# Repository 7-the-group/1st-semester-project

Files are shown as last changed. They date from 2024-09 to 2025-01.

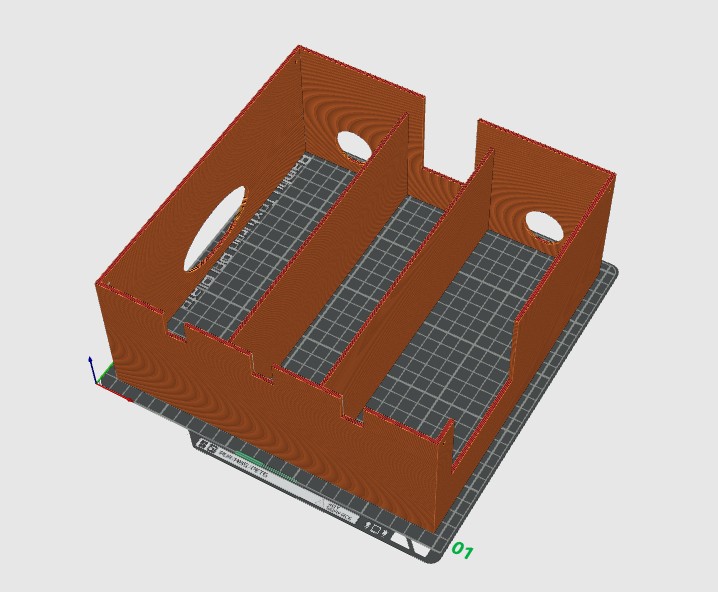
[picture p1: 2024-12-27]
report/figures/walls(3D-Print).jpg

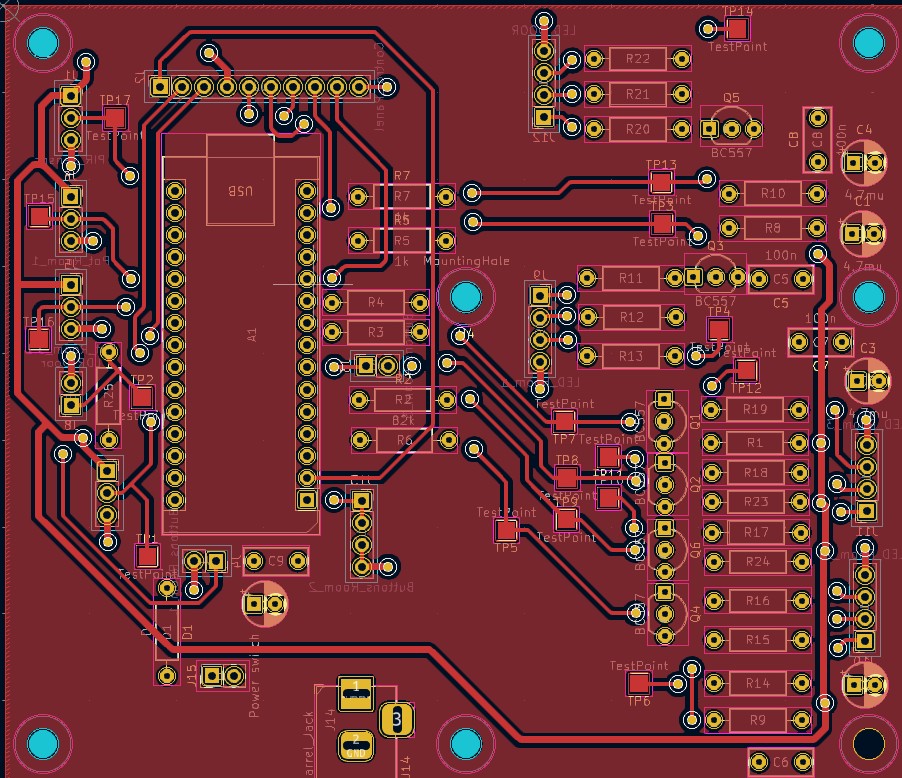
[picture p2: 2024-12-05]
Hardware/Schematic_and_PCB/Arduino Main PCB/arduino main fin/Toplayer.jpg

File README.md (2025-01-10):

# Group 7 semester project

# How to start

All the necessary parts are in Product folder. In Product/PCB there are two zip files for PCB manufacturing one is for PCB with the Arduino and the other one is for PCB with buttons. When PCBs are printed and assembled refer to the documentation appendices for correct connection.

In Product/Models folder you can find .stl files for control panel casing and base. We also created casings for potentiometers and buttons however those serve only esthetic function. Next there is .dxf file, which contains walls model for laser cutter.

Finally in Product/Software folder is PlatformIO project with all the necessary code, just upload it to Arduino.

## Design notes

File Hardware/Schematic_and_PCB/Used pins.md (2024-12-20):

LEDs need pins capable of generating PWM signal, in pinout pdf they are marked with '~'.

For LCD we need I2C pins.

For LDR and potentiometers we need analog pins, those are ones with 'A' prefix.

|Device|Device pin|Arduino pin|Port|
|----|----|----|----|
|LCD|SDA|D18|PC4|
|LCD|SCL|D19|PC5|
|Button up|-|D7|PD7|
|Button down|-|D8|PB0|
|RGB LED room 1|-|D9|PB1|
|Button ok|-|D11|PB3|
|Button back|-|D12|PB4|
|Potentiometer LCD|-|A0(D14)|PC0|
|Button room 1|-|A1(D15)|PC1|
|Light sensor door|-|A3(D17)|PC3|
|Potentiometer room 1|-|A6|ADC6|
|Red LED room 3|-|~D3|PD3|
|Button room 3|-|D4|PD4|
|Green LED room 3|-|~D5|PD5|
|Blue LED room 3|-|~D6|PD6|
|Buttons room 2|-|A2|PC2|
|Button sleep|-|D1 (RX1)|PD1|
|RGB LED room 2|-|D2|PD2|
|Potentiometer room 3|-|A7|ADC7|
|PIR sensor|-|D13|PB5|
|LED door|-|D10|PB2|

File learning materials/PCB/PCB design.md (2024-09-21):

# PCB design

For PCB design we can use [KiCAD](https://www.kicad.org/), [Eagle](https://www.autodesk.com/products/eagle/overview) or [EasyEDA](https://easyeda.com/).

KiCAD - I used KiCAD the most and I prefer it over Eagle also it is more beginner friendly, but now we have everything from autodesk for free I would try Eagle. KiCAD has built in 3D visualizer of PCB.

Eagle - We can use it in combination with [Fusion 360](https://www.autodesk.com/education/edu-software/fusion).

EasyEDA - This application is web based (but can be downloaded as an application). It is designed to be as easy as possible and you can directly order PCBs from [JLC-PCB](https://jlcpcb.com/) in EasyEDA

## Youtube channels and learning resources

[Phil's lab](https://www.youtube.com/@PhilsLab) - He is mostly using KiCAD and Altium designer.

https://resources.pcb.cadence.com/blog/2023-an-introduction-to-printed-circuit-boards

https://www.youtube.com/watch?v=MsdJgEinb34

We are not going to do very complicated circuits, so basic understanding of PCB design and orientation PCB design software should be enough.

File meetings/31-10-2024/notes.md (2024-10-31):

- button approved for printing
- Question: How to connect the components flexibly - jumper cables?
- Battery problem - fix with filtering or use power bank instead? - we will use Milan's power bank - permanent solution
  
PCB design:
- built-in - transistors, resistors, connectors  
- outside - LEDs, buttons, sensors (PIR,LDR), potentiometers, LCD  
 
PCB design assigned to:  
- Jakub - LCD PCB + footprints
- Kati  - Main PCB  
  
How to create libraries 
- .h(declarations) and .c(definition) file
- .h file should have at the start #pragma once or stuff with #ifndef

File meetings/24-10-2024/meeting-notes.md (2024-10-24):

- 3d models and calculations should be ready by Monday
- hardware & circuits tested: lcd, rgb led, photoresistor, pir sensor
- for photoresistor circuit - voltage divider is used
- problems with pir sensor testing, code did not work

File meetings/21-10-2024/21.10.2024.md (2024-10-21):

## Changes in PCB
We settled down on using two potentiometers in room 3 and we connect buttons in room 2 in parallel so they occupy only one pin. Last pin can be used for button for sleep or other functionality.

## 3D model of the house
We diced to route cables in a hollow floor. Overall design has one corridor in the middle and two rooms on the sides. Corridor is the room 2 at the same time.

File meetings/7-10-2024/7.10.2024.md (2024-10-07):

We decided on parts to buy and agreed on using KiCad for PCB design.

Parts are in components.xlsx file.

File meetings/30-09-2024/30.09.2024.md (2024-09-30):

- We will use knob on a LCD display.
- Everyone should write their own list of parts he/she need.
- 

## We decided on a diode
Kingbright Lysdiode 4 ben Hulmontering trefarvet LED RGB 465 / 525 / 630 nm 900 mcd, 1300 mcd, 3600 mcd 2,5 V, 4 V 50°
(https://dk.rs-online.com/web/p/lysdioder/8614290?gb=s)

## We decided on a transistor
BC547

## Parts
- 4x RGB LEDs 
- 1x Knob
- 6x transistors
- 4x buttons for LCD
- 4x light switches (buttons)
- 1x light sensor
- 1x PIR sensor (sensor for movement)
- 3x potentiometers

## Optional parts
- 4x humidity/temperature sensors

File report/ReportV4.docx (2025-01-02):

# Smart home model

Authors:

Milan Caban

Jakub Dubrava

Katharina Lea Johannsen

Roko Grgic

Danylo Lysechko

Yumna Ayesha

# 1 Abstract

This semester’s project focused on designing and building a functional smart home model equipped with a centralized control panel for managing room-specific features such as lighting and PIR sensor. The model demonstrates how modern technology can enhance convenience, energy efficiency, and user interaction within residential spaces. Since this is a first experience with electronic product design for most of the members, we expect that this journey will teach us a lot about electronics and teamwork.

# Table of Figures

# 2 Introduction

This report encompasses various procedures involved in construction of a smart home model. One of the initial definitions of smart home is provided by Lutolf, defining it as “an integration of different services within a home by using a common communication system.” Moreover, it should assure „an economic, secure, and comfortable operation of the home and include a high degree of intelligent functionality and flexibility.” (Lutolf, 1992) A fresher definition by Satpathy states, that “a home which is smart enough to assist the inhabitants to live independently and comfortably with the help of technology is termed as smart home. In a smart home, all the mechanical and digital devices are interconnected to form a network, which can communicate with each other and with the user to create an interactive space.” (Satpathy, 2006) We consider this definition more proper, as it emphasizes the role of network in smart home systems, in contrast to the vaguer term ‘common communication system’ used by Lutolf.

According to Zielonka, one of the major development trends related to smart homes are healthcare and quality of life, security in data management and optimal energy management and sustainability. Presumably, the trend of energy management and sustainability is intertwined with recently rising ecological trend (Zielonka, et al., 2021). However, the graph in Figure 1 shows that advanced lighting and intelligent energy management are not amongst the most influential trends. Nevertheless, the upcoming paragraph underlines the significance of innovation in this sector.

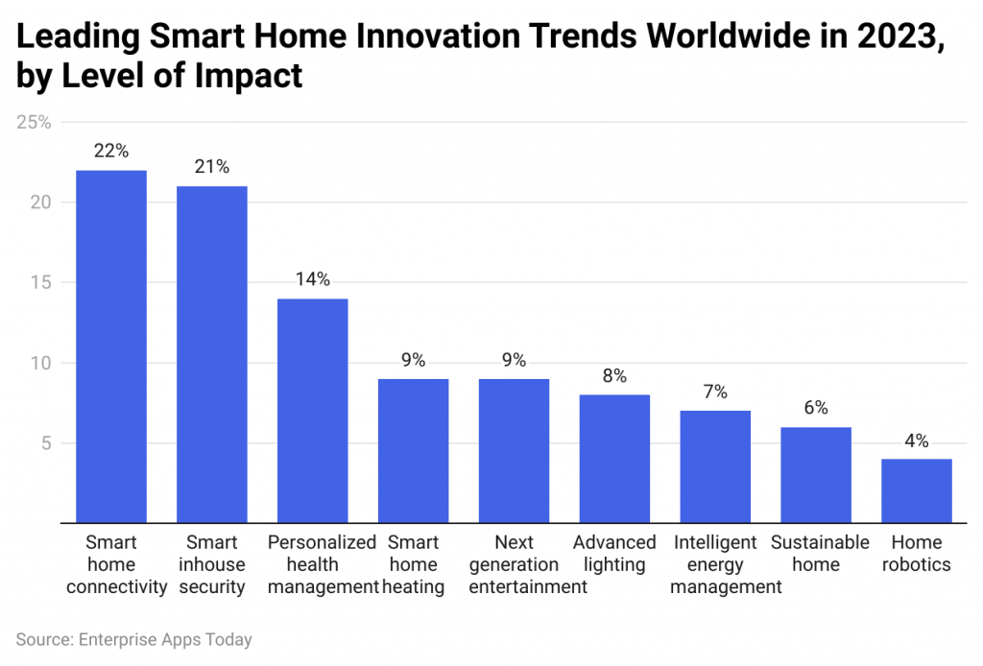
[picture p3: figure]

Figure 1 Graph of Leading Smart Home Innovation Trends Worldwide in 2023

The use of LEDs as an illumination component is crucial not only for lower energy consumption in comparison to conventional lightning bulbs. According to Schratz, “when compared to incumbent lighting technologies, most LED fixtures deliver at least a 50% improvement in energy savings, which translates directly into significantly lower carbon emissions and a much smaller environmental impact”, while they offer more advantages such as “less heat output, lower risk of ignition due to dust and particle accumulation, improved color rendering for a better quality of light, and negligible UV light output, which reduces insect infestation and product deterioration”. Remarkably, its life-span can reach “more than 100,000 operating hours”. (Schratz, Christine, Struhs, & Gray, 2016)

Although lights with movement sensors are commonly used nowadays, they could benefit from integration into a centralized system, bringing everything ‘under one roof’. The main advantage of a system with a centralized unit is its flexibility, as users would be able to manipulate light status manually inside the house as well as through communication with the centralized unit, for instance via a control panel. New features could be implemented, for example allowing the change of various thresholds according to user’s needs easily and any time.

However, many challenges emerged during the design process. The most significant problems can be summarized in several ‘how to’ questions:

1. How to construct the house?
2. How to adjust the intensity or color of the light?
3. How to assemble and integrate the circuits?
4. How to structure the control panel menu?

Mentioned questions are answered in subsequent 8 sections. The third chapter includes detailed steps of the design process, where any decision is complemented by justification. The fourth section concerns the final product, possibly deviating from the planned design. The fifth section contains comparison of design and result as well as technical limitations. Moreover, the sixth section provides a concise conclusion on the whole project. References and appendices are placed in the last two sections.

# 3 Methods

## 3.1 Circuit design

### 3.1.1 Control panel PCB

We chose to have a Control panel, because according to Alam, a characteristic of a smart home is that it can be controlled remotely from outside the home. (Alam, Reaz, & Ali, 2012) The control panel could be developed further to be wireless with Bluetooth and controlled via an app.

For the Control panel, we chose to use buttons to navigate in a menu displayed on the LCD.

A Potentiometer was planned to control the RGB Values and the brightness of the LEDs.

We incorporated 5 buttons UP, DOWN, OK, BACK and a Button for an extra function (sleep mode).

The 4k7 Ω Resistors function as Pull up Resistors for the I2C Module of the LCD.

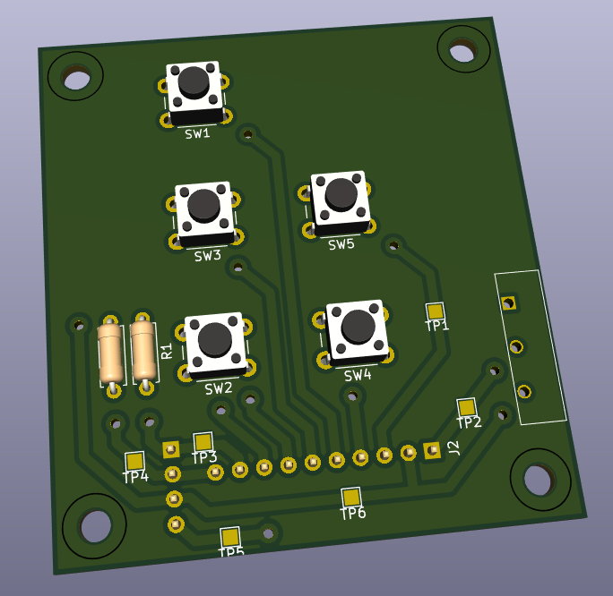
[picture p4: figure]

Figure 2 Control panel PCB 3D model

### 3.1.2 Main PCB

We decided to have the components in and on the house (switch-buttons, LED, Potentiometer, Sensors) connected to the PCB with pin header connectors. So, the PCB is detachable from the House. We Further divided the circuit in two PCB’s. One for the Control panel, with the Buttons and Potentiometer mounted on the PCB via Through hole soldering and a pin header connection to the Liquid Crystal Display (LCD).

The other PCB has the transistor driver circuit for the LED's, circuits for the Sensors and the microcontroller on It.

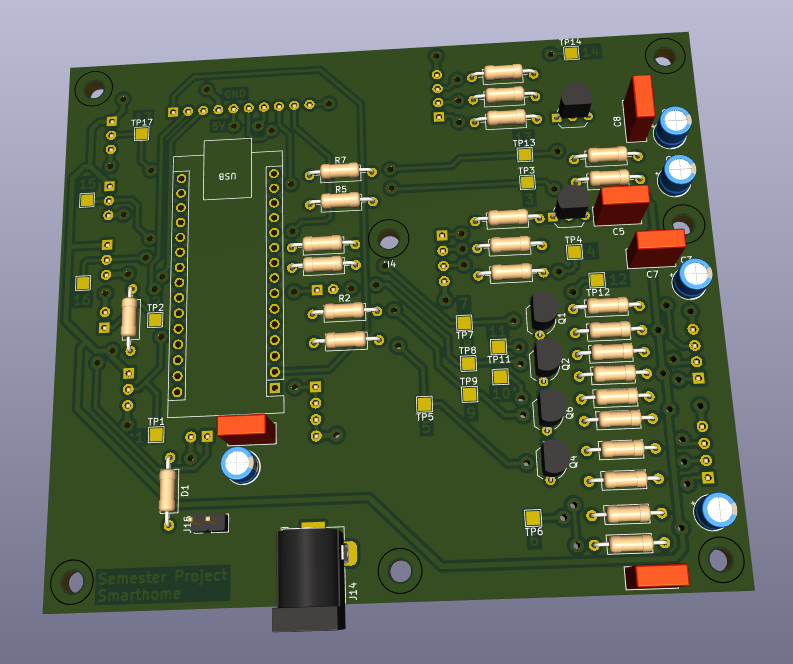
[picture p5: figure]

Figure 3 Main PCB 3D model

## 3.2 3D-Modelling

The design of the house can be divided into two categories, one is base and the other are walls and floor.

The base was designed in Fusion 360 for 3D printer. The whole model consists of 230mm X 230mm square with three rooms. We also added mounting holes for walls and floor and space under the floor is empty for routing cables, for that reason we also added openings at the back near the control panel.

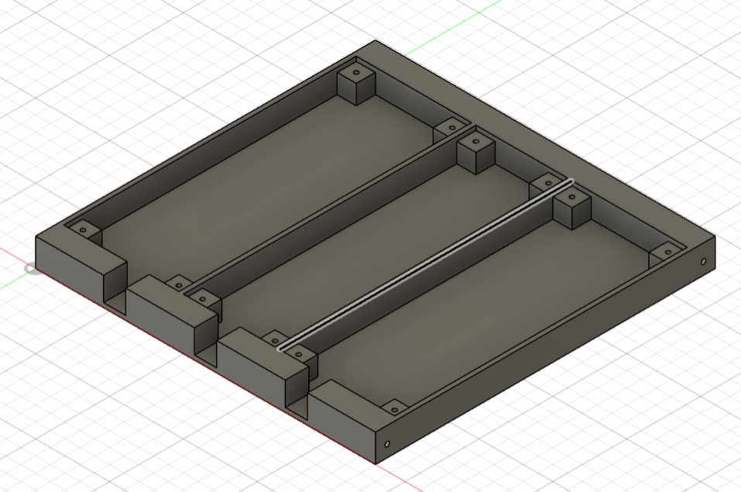
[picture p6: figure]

Figure 4 Base 3D model

Walls and floor were designed in Fusion 360 as well, but they were designed for a laser cutter. After laser cutting some parts had to be treated using a rasp so they fit together, because some connections are angled 45 degrees for stronger fit.

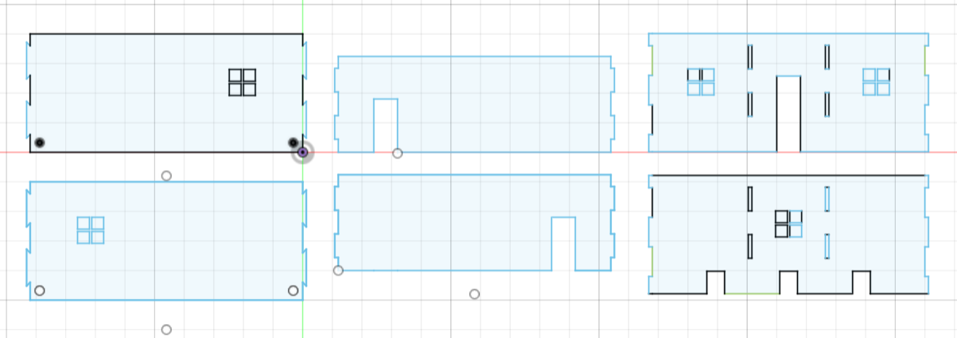
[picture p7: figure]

Figure 5 Walls and floor model

For slicing we used Bambu Studio and printed it as well with a Bambu 3D printer.

## 3.3 Assembly of the Model

After receiving the drilled PCBs, we checked the connections with a multimeter.

Because the PCBs had no connection errors, we continued with the next step: soldering the PCBs.

To have more space underneath the PCB when placing it on the table, we first soldered some of the pin headers to make it stand stable while soldering the vias.

Then we soldered the components starting with the flattest and ending with the tallest.

We reused the female-to-female jumper cables to create the wiring to the components in the house. So, the cables were cut in half and soldered to flex wire around 475 mm in length. Then the flex wires were soldered to the components according to the color-coded wiring table. We used shrinkable tubes to isolate the soldered wire to prevent short circuits. Now with the wiring the entire system and code could be tested.

The Control Panel PCB was mounted with four M3 x 40 mm screws and 20 mm long spacers on to the Mainboard.

Where the LEDs should go, 5mm holes got drilled in the walls for the Lens to go through. To mount the LDR sensor and the PIR sensor, holes were drilled in the outer walls as well.

To arrange the LEDs, buttons and sensors in the house, it was marked where the wires go through the floor. According to that, the floor plates got holes drilled through the wood.

With the components placed on the walls, the female connectors were thread through the holes in the floor, routed at the bottom and lead to the casing of the Control Panel.

The LCD was mounted to the lid of the control panel casing with four M3 x 10 mm screws and nuts.

With all the connections according to the wiring table, the casing of the control panel could be closed and the walls screwed to the bottom with four 3.5 x 25 mm spax screws. To fix the wires on the walls we used electrical tape.

## 3.4 Problems during assembly

On the Main PCB connection issues and other connection issues were discovered while testing the connections with a multimeter. We fixed the problem with resoldering the visual faulty solder joints.

We realized that D0 was just connected on top layer on the Main PCB Layout, a via was forgotten to be placed in front. Fortunately, it was not relevant for the main functionality because it was meant to be for an optional button to start an extra function.

The Wire for Room 1 Button was swapped with Room 1 Pot, because the IO Pin A6 formerly assigned to Room 1 Button can only be used analog.

The Potentiometer on the control panel was not implemented because it was more convenient to code the user interface only with buttons.

The Pin D1/RX was not able to be used because it interfered with serial communication (RX/TX), even without being connected to a PC. That was probably caused by the USB C connector circuit on the microcontroller. D1 was originally used for button room 2 but then changed to A2. Because J5 had just one pin connected to A2, the two wires of the buttons in parallel were soldered to one female connector.

## 3.5 Introduction to software

Our first idea was to create a library for every room, door and control panel. The library should implement “Init()” and “Update()” functions which will be called in main function. In addition to them, we also implemented some functions which control the state of the room directly, for example they turn the light on and off. This approach made code more maintainable and readable, therefore we used it in our final build. Also, we could very easily divide individual code parts to team members, in our case everyone had to program one room.

Figure 6 Main program

We had to come up with a solution to how buttons should operate in rooms where there is the possibility to change brightness or color of the light. After a few discussions we stuck to the idea that the last action takes effect. This means that if brightness was set to half of its potential by clicking the button the light is turned off (light is set to maximum brightness after clicking button, only when brightness is zero), even though the potentiometer’s value stays unchanged. This solution turned out to be very handy when we started working on the control panel.

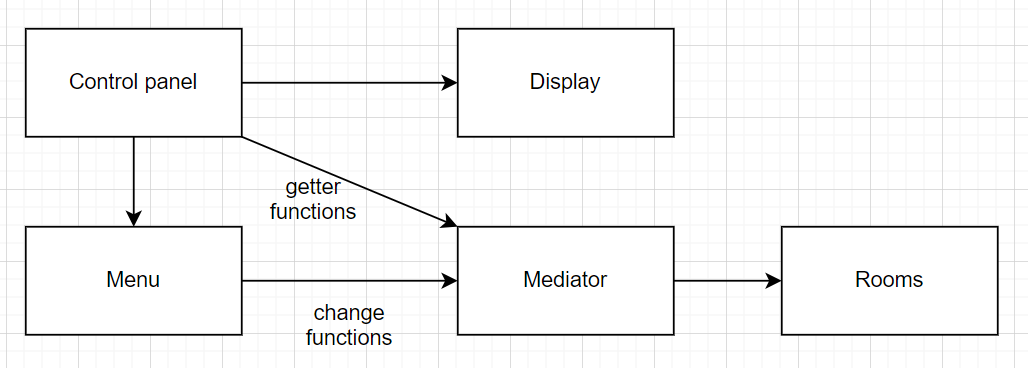
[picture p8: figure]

Figure 7 Software diagram

When a button is pressed the change from not being pressed and being pressed isn’t immediate, there are always some fluctuations which are the result of mechanical construction of a button. We solved this issue by adding delay every time a button is pressed, this resulted in functions for every button which check status of a button and if it is pressed, they start a 100 ms delay.

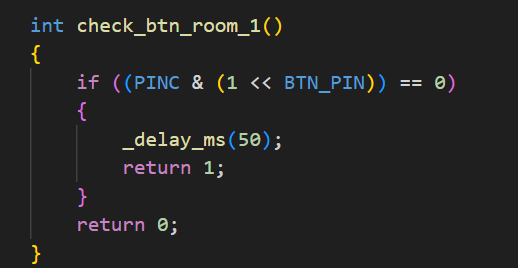
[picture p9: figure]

Figure 8 Check button function

## 3.6 Room 1 software

Room 1 has one button for turning the LED on and off and one potentiometer for controlling the brightness of the LED. We implemented functions for controlling and retrieving information about the LED’s status and brightness.

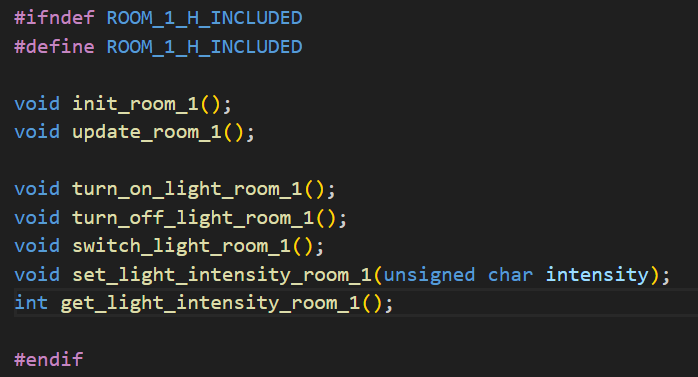
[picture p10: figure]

Figure 9 Room1.h

In “Init()” we initialized ADC and PWM using Alin’s libraries and set button pin as input with pull up resistor. To do that we referred to AtMega datasheet (Atmel Corporation, 2015) and Arduino Nano pinout (Arduino cc, 2021). We used these documents for other rooms and control panel as well.

“Update()” function checks if potentiometer values changed since last measurement, if yes update LED’s intensity accordingly. Then it checks if button is pressed and wasn’t pressed previously, if this statement is true then the status of LED is inverted.

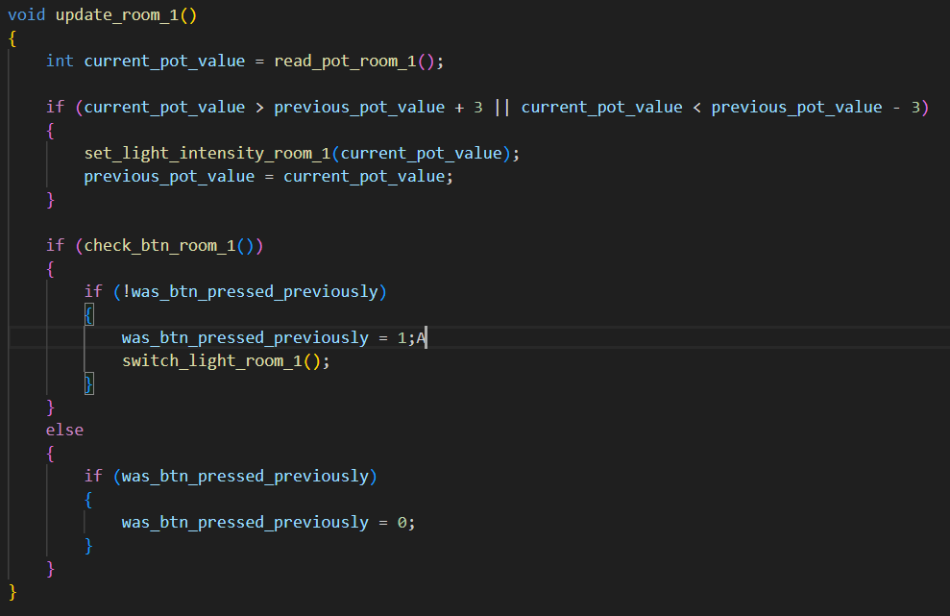
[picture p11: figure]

Figure 10 Update room 1 function

## 3.7 Room 2 software

This is the simplest room, it has only two buttons and one LED. Since we wired buttons in parallel, from the Arduino perspective they act as a one button. Again, we added functions for getting and setting status of the LED. Logic in “Update()” and ”Init()” is very similar to Room 1, just without potentiometer and LED is controlled using registers not using the PWM library.

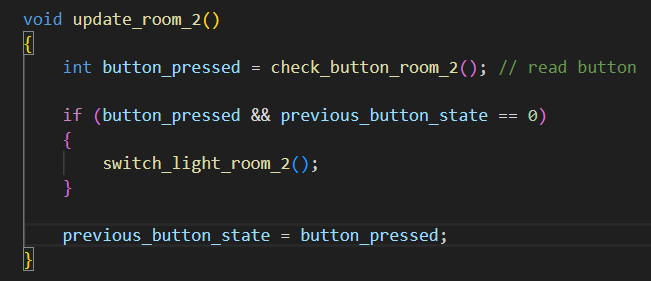
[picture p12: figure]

Figure 11 Update room 2 function

## 3.8 Room 3 software

Room 3 contains one potentiometer for color changing, a button and one LED. We decided that potentiometer will affect only one property of the light, for example red or green.

We were aware of the limitations of this approach and decided to implement configuration of a potentiometer’s-controlled value into control panel, in final version it is possible to choose which part of the light’s color is controlled by a potentiometer. We also added HSV (Atkins, 2010) color model because it is much easier to work with for people. So, you can configure red, green, blue, hue, saturation, value whilst hue is default.

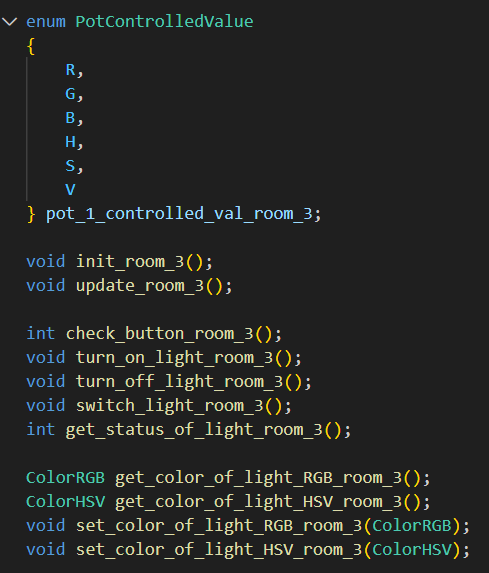
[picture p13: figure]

Figure 12 Room3.h

The potentiometer is read the same way as in the room 2 and LED is controlled using PWM 3 from Alin’s library, turning on and off using the switches between full white and completely off.

## 3.9 Door software

Door’s LED is controlled by PIR sensor and LDR, therefore there is no button. In addition to “Init()” and “Update()” functions we implemented functions for detecting movement, getting current value of LDR and setting threshold for LDR.

In “Init()” function we just initialized ADC using Alin’s libraries and pin for LED as output and pin for PIR sensor as input using registers.

Every time the movement is detected and LDR has higher value than threshold, LED is turned on and timer is reset. Timer is just one variable which is incremented by one every time the “Update()” function is called, when the LED is turned on the variable is set to zero, when this variable reaches particular value LED is turned off.

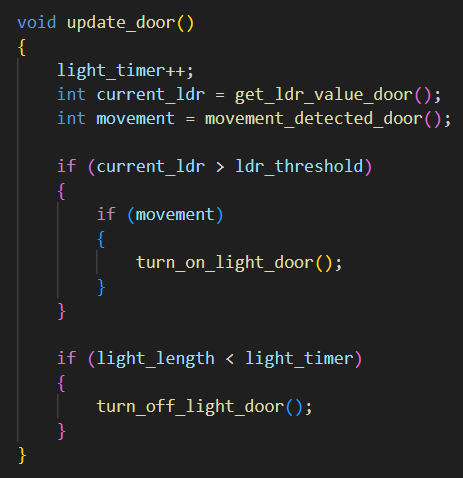
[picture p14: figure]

Figure 13 Update door function

## 3.10 Control panel software

Even though it is not a room, it works very similarly to one, because buttons function the same as in the rooms and control panel and background logic is just a more complicated version of a LED.

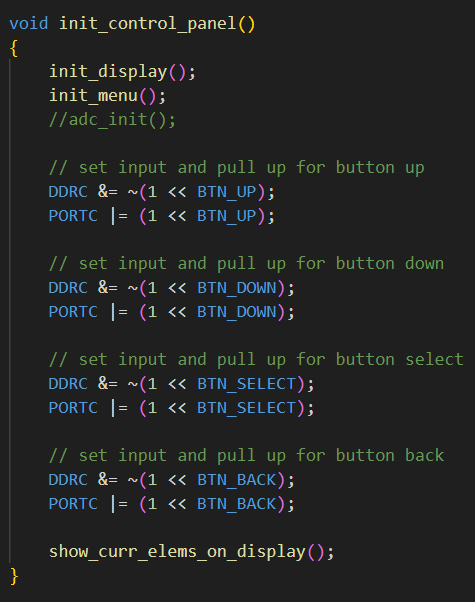
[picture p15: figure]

Figure 14 Init control panel function

In addition to physical components, which make up control panel, we had to implement back-end logic for the menu responsible for storing and navigating in menu elements, we also implemented some type of a link or connection between control panel and rooms, we called it mediator.

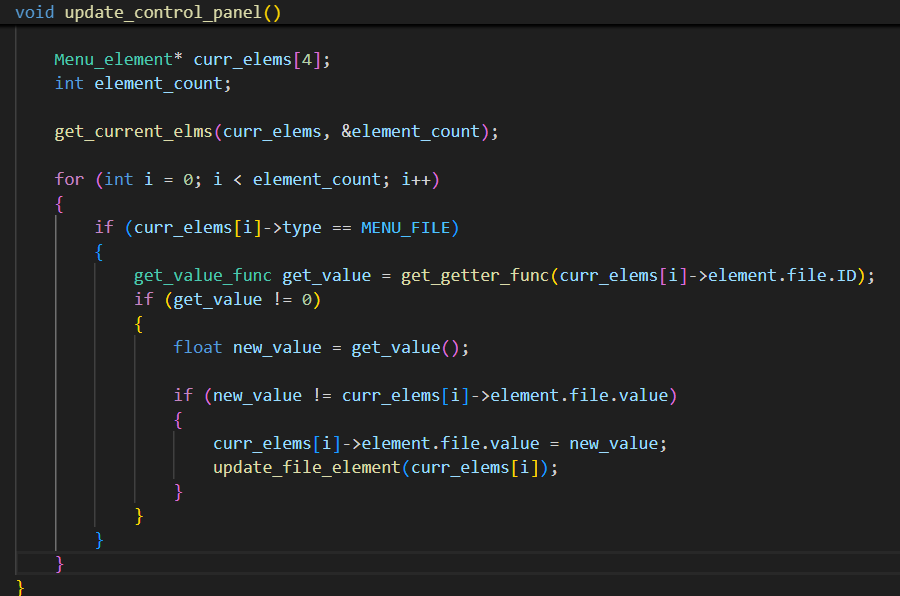
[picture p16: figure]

Figure 15 Part of the update control panel function

Mediator’s responsibilities are to retrieve and change information for room associated with menu element, for example for element showing status of LED in room 1, mediator will return status of led in room 1 and element will be updated, when value in menu element is changed mediator ensures that room is updated as well.

### 3.10.1 Menu implementation

When we were designing a menu, we took inspiration from files and folders in a computer, every element in a menu can be file or folder.

Folder contains more folders or files, for example at the top level of the menu there are four folders (room 1, room 2, room 3, door) after selecting one of the folders its content will be displayed on control panel. Returning to a previous folder is done by clicking “back” button.

Files hold values which can be linked to room, or it can be some arbitrary value which affects other files for example file “Color format” can have value “RGB” or “HSV” (Atkins, 2010) and this value affect how is color of the light in room 3 represented on control panel. After selecting file its value can be changed by clicking “up” and “down” buttons, changes take effect instantaneously. File can be deselected by clicking “back” button.

Files and Folders are contained in “Menu_element” struct (W3Schools, C structs, n.d.) this struct has a variable of enumeration type (W3Schools, C enums, n.d.) to determine if current menu element is file or folder, after this variable is union (TutorialsPoint, n.d.) with file or folder struct in it. The only differences between folder and file structure are that file has also value, type of data stored in it and variable which determines if it is selected.

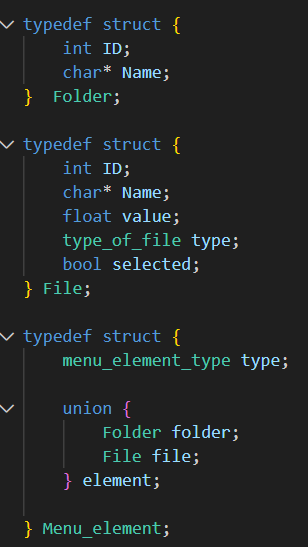
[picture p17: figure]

Figure 16 Menu structs

Our first idea for storing menu elements was to use multidimensional array, but we quickly realized that it would be difficult to work with it, because we can’t determine the size of an array in C, and we risk going out of bounds of it. For that reason, we stored all the elements in one dimensional array and location of the element we encoded in its “ID”.

ID acts as a path to the element for example after clicking second folder on first level first element on second level will have ID equals to 12, path is inverted (first level is last digit and last level is first digit) so it is easier to search in array of elements.

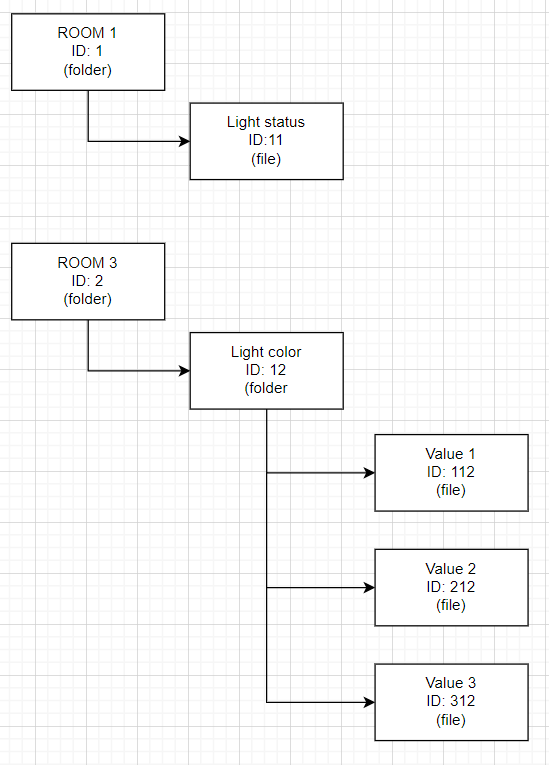
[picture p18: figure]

Figure 17 Menu diagram

### 3.10.2 Display implementation

To simplify the use of display we created helper library, which has functions for updating whole display with menu elements, which are passed to the function as a parameter, and for updating one element, so display is not refreshed every time a value in one element is changed only that element is refreshed.

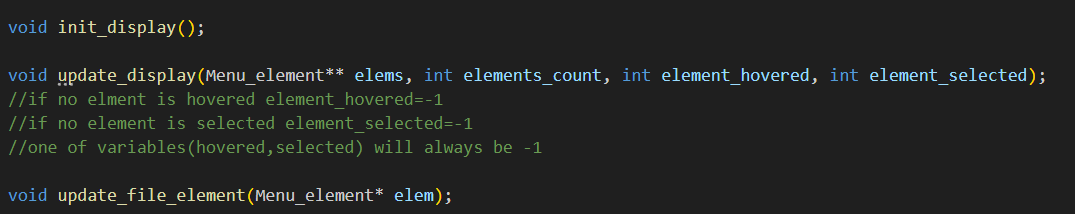
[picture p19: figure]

Figure 18 Display.h

I addition to displaying current menu elements, display also mark hovered element with “*” character and selected element with “>” character.

### 3.10.3 Mediator implementation

As it was mentioned in previous chapters, to update rooms using control panel we are using Mediator. Mediator’s API consists of two functions which return pointer to a function one returns a function for changing value and the second one returns a function for getting a value. Which function to return is determined by menu element ID, functions aren’t stored in an array, pointer to a particular function is returned using switch statement (W3Schools, C switch, n.d.) which switches between different IDs.

Figure 19 Mediator.h

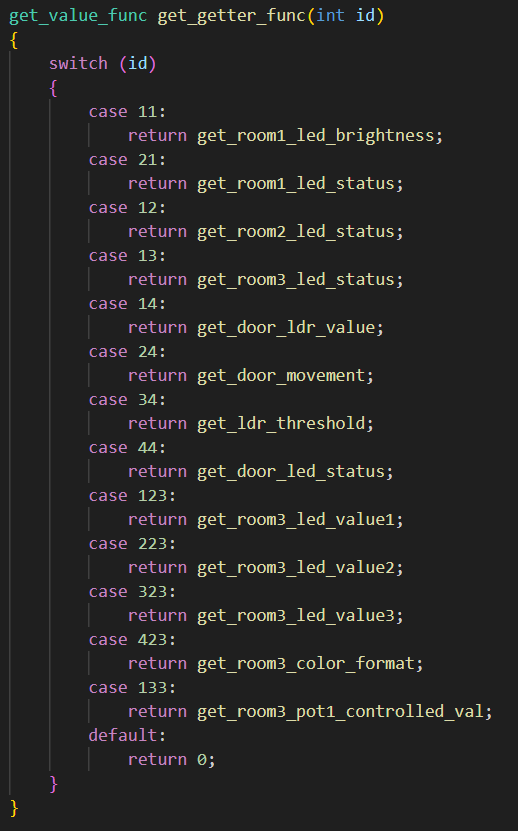
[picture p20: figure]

Figure 20 get_getter_func function

## 3.11 Software problems

When debugging the whole assembly we encountered some issues, those problems were mostly logical and easily fixable. However, we couldn't fix problems with altering the color of light in room 3 using control panel when color format was set to HSV (Atkins, 2010), therefore this feature is not available and can be changed using control panel only when color format is set to RGB.

Another inconvenience which made its way to the final product is unreliable control of the status of light in door, which means that door light can be controlled by control panel, but it does not work every time, we couldn’t figure out why it happens.

# 4 Results

In hindsight we can say that the project went well, even though we found ourselves in a hurry at the end, due to unexpected problems and difficulties.

Our main focus when designing smart home was on connectivity and ease of controlling individual rooms. We achieved this by incorporating a control panel whilst perceiving ability to control rooms in place. When working on the control panel we focused on making it as intuitive as possible, therefore we used the approach the last action takes effect. This way you don’t have to worry whether the light in a room is turned on or off because you can always set it in a room or in the control panel.

When designing the hardware part of the project we thought about how to route cables a lot, we wanted simple solution, which allows us to make mistakes when routing in terms of length of cables. By making the floor hollow we were able to route all the cables easily while having space for very long cables. Since all the cables are in the floor, we were able to use a laser cutter to cut walls which was a faster and easier way to manufacture walls.

When it came to software, we didn’t want to write everything in one file and somehow make it work, because this way the code would become unreadable very quickly and possible problems would be very difficult to solve. Therefore, we created a library for every room and in the main function we just initialized and updated the room. In addition to room libraries, we created some helper libraries for the menu, display and mediator. As a result, we had a very clean and maintainable code base, which made it much easier to find and fix bugs.

# 5 Discussion

This section contains explained differences between results and design, limitation of the project and suggestions for further development.

## 5.1 Design and results comparison

Overall, the design functioned as expected. Nevertheless, some features had to be abandoned, as their functionality was not required. Notably, the use of RX/TX or D0/D1 pins turned out to be complicated. Their behavior is different in comparison to standard digital pins, which was found out later in the project. Therefore, they are not used in the final version of the project. In addition, the button for additional features, initially intended as a switch to turn on or off sleep mechanism, could not have been implemented due to a design flaw. It is described in section 3.4 Problems during assembly.

What’s more, it was decided that the control panel potentiometer will not be used. It was intended as a tool to change brightness or color component directly on the control panel, however, such implementation proved to be more complex than the implementation of this function to the control panel buttons. Another neglected feature is the ability to change color components in HSV format, in Room 3 via the control panel. Presumably, the adjustment of the color values was faulty due to unknown causes likely stemming from coding errors. The displayed format of the color in Room 3 menu can still be changed, but the ability to adjust color values through control panel is solely available in RGB format.

## 5.2 Technical limitations

Moreover, some of our decisions were not optimal due to a few restrictions. One of the restrictions were mandatory requirements of the project, namely the use of Arduino Nano microcontroller and LCD display provided by the SDU. However, these requirements weren’t and shouldn’t be considered as true restrictions within the context of the project. The aim of this remark is to acknowledge these requirements, as they fundamentally influenced the development process. In addition, other confinements were introduced by electrical component provider and PCB manufacturer. The choice of electrical components was restricted by the limited variety of component models sold by the provider, while the design of PCBs had to align with available services of PCB manufacturer.

## 5.3 Retrospective

Furthermore, the dynamic of a newly formed project group affected the whole development process. The project plan design was unrealistic, as the capabilities of the members didn’t match the task skill/knowledge requirements most of the time as well as the pace proposed by the plan was too high. However, due to the high frequency of group meetings, there was consistent work done each week and any problems could be resolved quicker. Arguably, a thorough plan was not required to efficiently finish the project due to a few factors. For example, members were new to the concept of working in group on such a technical project, members weren’t familiar with all the aspects of the development process, but most importantly, cumulative acquisition of knowledge didn’t allow smoother completion of tasks during the whole semester. Nevertheless, a group would benefit from more frequent assignment of deadlines to the tasks emerging during the meetings. Notably, this section is not objective and is written from the writer’s perspective. The opinions of other members on this topic might significantly differ.

## 5.4 Discussion conclusion

To conclude, a couple of insignificant features included in the design weren’t implemented due to various reasons. Various sources of technical limitations were mentioned. The group dynamic is brought up as a factor influencing the development process, while the requirement of a strict project plan is challenged.

# 6 Conclusion

In conclusion, the finished prototype satisfies all requirements. Regarding materials used for the construction of the model, medium-density fiberboard (MDF) can be used as a material for models due to its low manufacture time and high customizability, while polylactic acid (PLA) is more suitable material for more complex shapes like threads thanks to the 3D printing.

Moreover, PWM can be utilized for adjustment of color or brightness of LED, while transistor can be used as switches and amplifiers of current. Printed circuit boards (PCB) are a practical option for placing circuitry, while capacitors are able to reduce signal distortion.

Higher readability of code and easier assignment of coding tasks can be achieved by having multiple libraries each for different sections of smart home. In addition, computer file organization served as essential inspiration during the development of a menu structure.

High frequency of group meetings contributed to consistent progress. However, sensible deadlines could potentially enhance workflow in the group.

What’s more, members are now familiar with the development of a technical project encompassing various aspects, while acquiring new knowledge and skills. Amongst newly acquired skills are: 3D design, circuit design, improved soldering, improved coding abilities and many more.

All in all, the project greatly contributed to the evolvement of members’ hard and soft skills, while it familiarized them with the dynamic in a project group. The contributions of each member are shown in a table in Appendix 8.12.

# 7 References

Alam, M. R., Reaz, M. B., & Ali, M. A. (2012). A Review of Smart Homes—Past, Present, and Future. IEEE.

Arduino cc. (2021). Arduino Nano pinout. Arduino cc.

Atkins, R. (2010, December). RGBConverter. Retrieved from GitHub: https://github.com/ratkins/RGBConverter

Atmel Corporation. (2015). ATmega328P datasheet. San Jose: Atmel Corporation.

Lutolf, R. (1992). Smart Home concept and the integration of energy meters into a home based system. Seventh International Conference on Metering Apparatus and Tariffs for Electricity Supply 1992 (pp. 277-278). Glasgow: IET.

Satpathy, L. (2006, 5 8). Smart Housing: Technology to Aid Aging in Place - New Opportunities and Challenges. Retrieved from Thesis and Dissertations: https://scholarsjunction.msstate.edu/td/3967/

Schratz, M., Christine, G., Struhs, T. J., & Gray, K. (2016). A New Way to See the Light: Improving Light Quality with Cost-Effective LED Technology. IEEE Industry Applications Magazine, 55-62.

TutorialsPoint. (n.d.). C unions. Retrieved from TutorialsPoint: https://www.tutorialspoint.com/cprogramming/c_unions.htm

W3Schools. (n.d.). C enums. Retrieved from W3Schools: https://www.w3schools.com/c/c_enums.php

W3Schools. (n.d.). C structs. Retrieved from W3Schools: https://www.w3schools.com/c/c_structs.php

W3Schools. (n.d.). C switch. Retrieved from W3Schools: https://www.w3schools.com/c/c_switch.php

Zielonka, A., Woźniak, M., Garg, S., Kaddoum, G., Piran, J., & Ghulam, M. (2021). Smart Homes: How Much Will They Support Us? A Research on Recent Trends and Advances. IEEE Access, 26388-26419.

# 8 Appendices

## 8.1 Main PCB

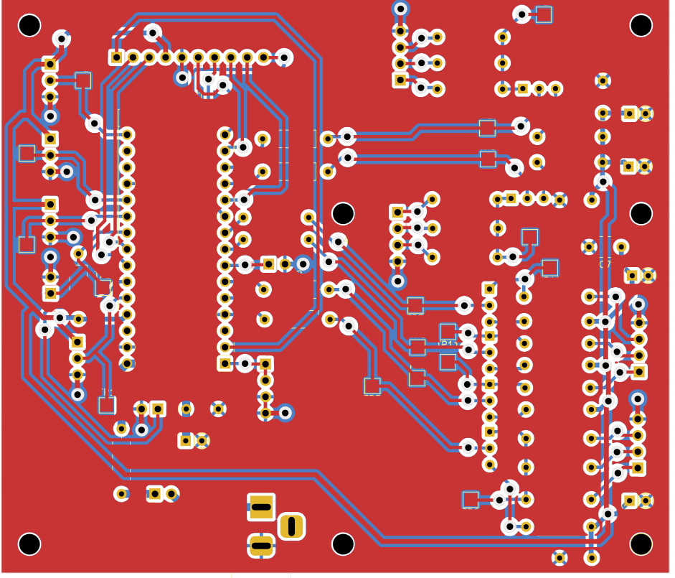
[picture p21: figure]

## 8.2 Main board schematic

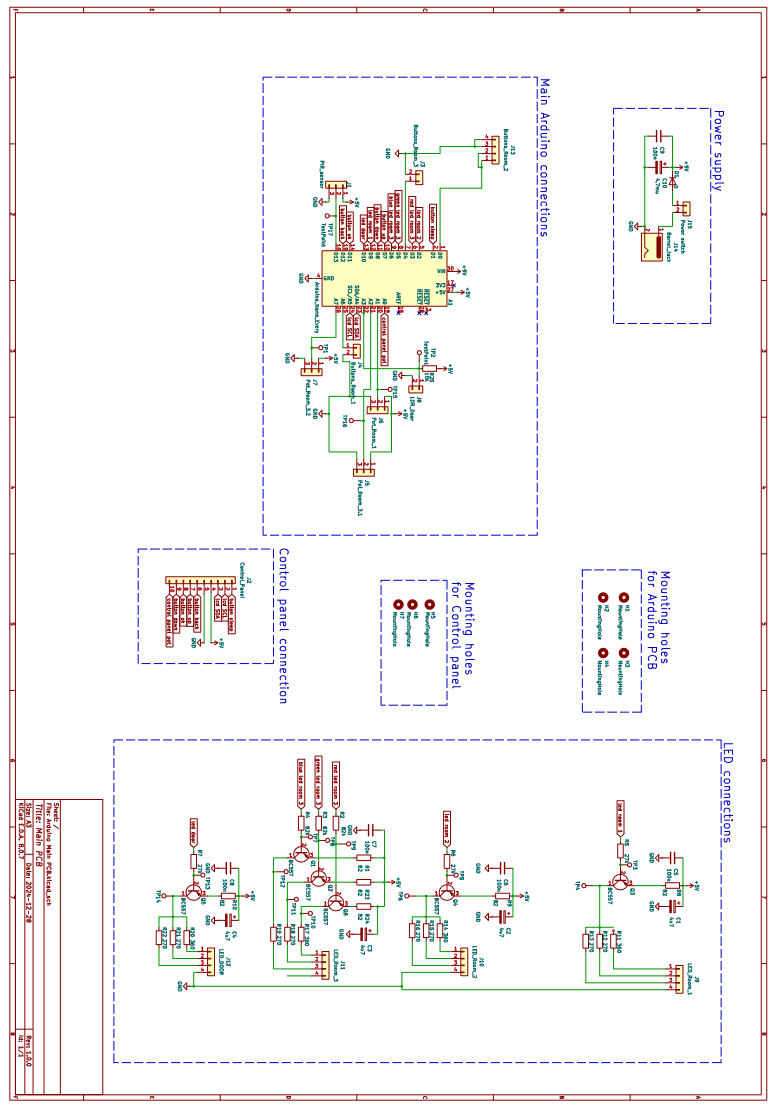
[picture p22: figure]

Control panel PCB

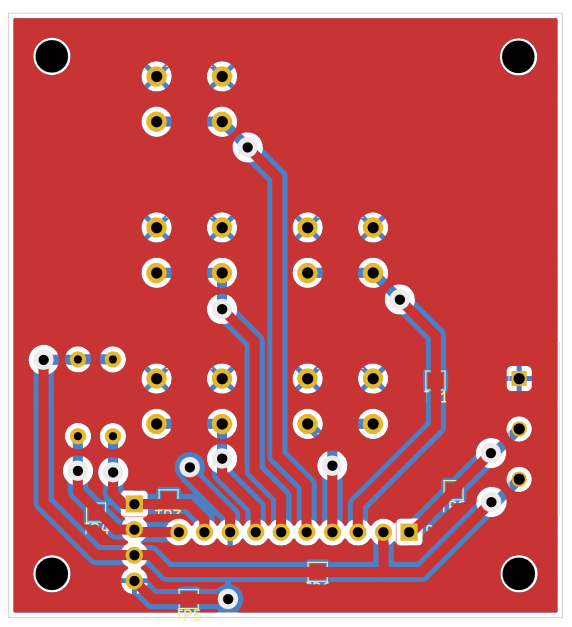
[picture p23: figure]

## 8.3 Control panel board schematic

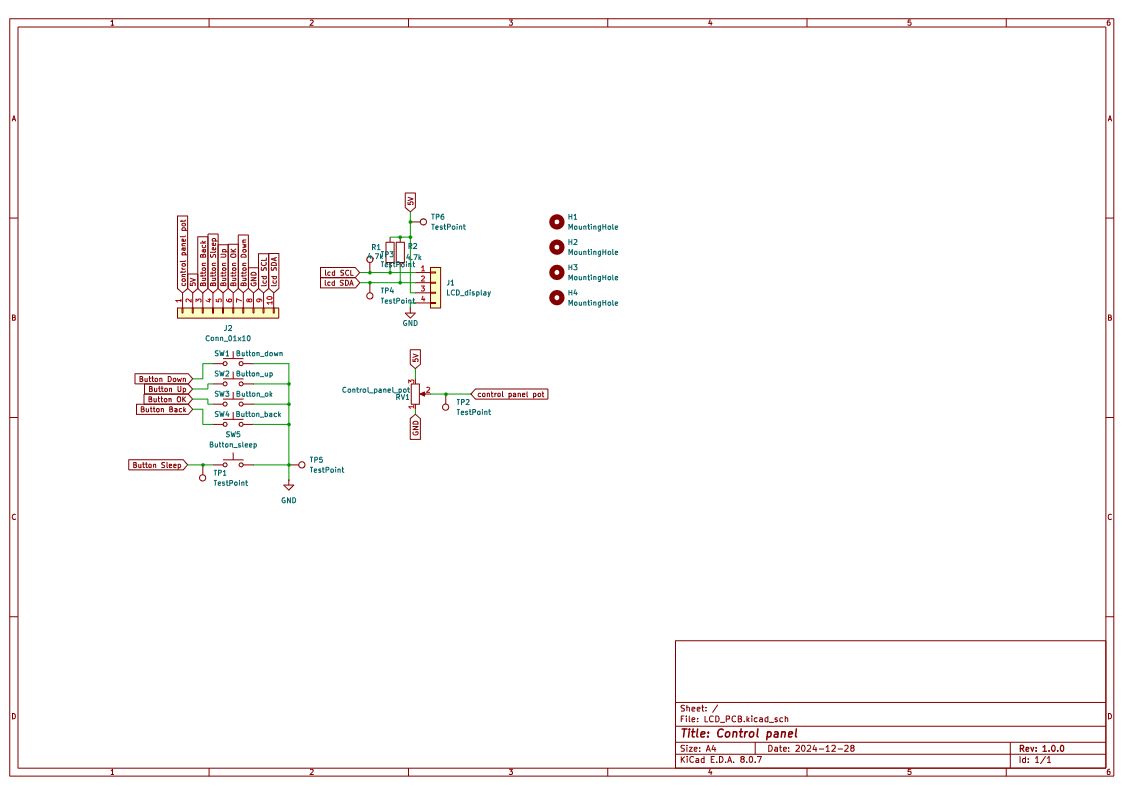
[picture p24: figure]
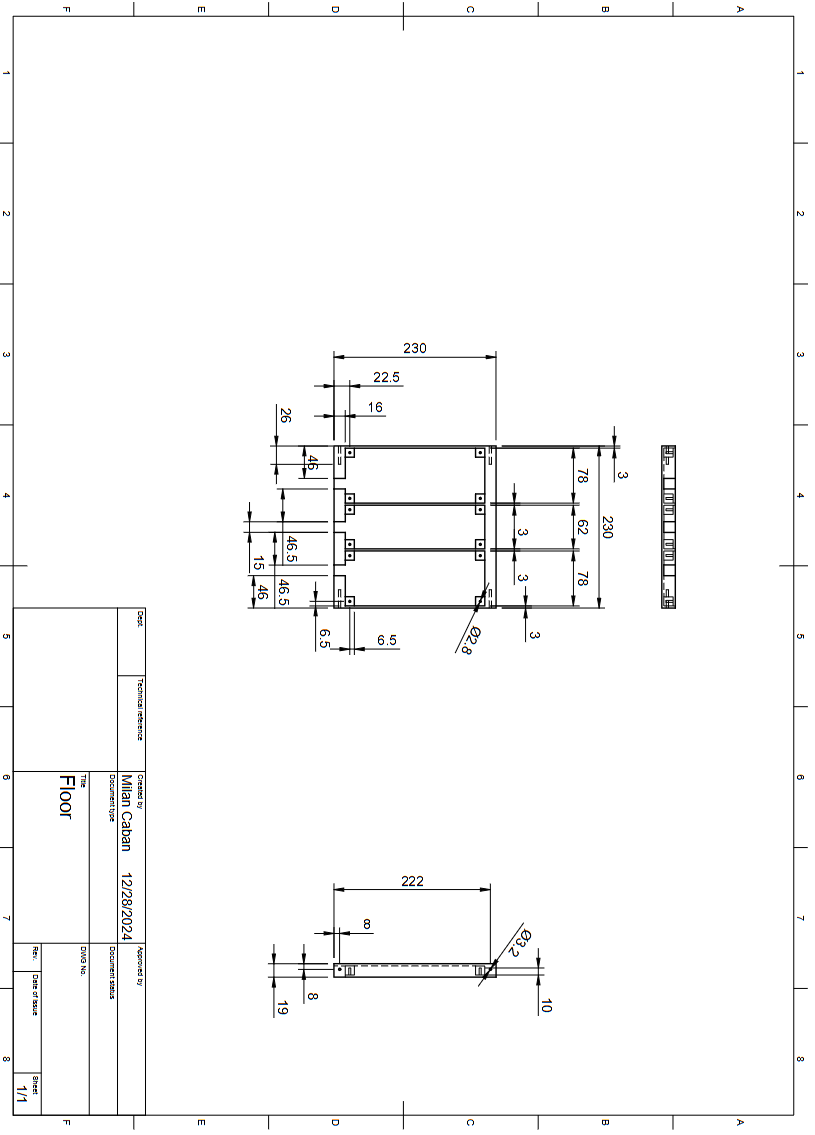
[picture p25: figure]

## 8.4 Base drawing

## 8.5 Button casing drawing

## 8.6 Calculations

If I_c = -10 mA (Room 3 Base resistor calculation):

v_(CE-sat) = -75 mV

h_(FE-min) =180

I_B =(I_C)/(h_(FE-min))= -0.01/180= -55 μA

R_(bb) =(v_(cc) -v_(BE))/(I_B)=(-5-(-0.7))/(-5.5∙10^(-5))=78.2 kΩ

v_(Resistor) =v_(cc) -v_(CE-sat) -v_(LED)

v_(Red LED) =-1.85 V

v_(Green LED) =-3 V

v_(Blue LED) =-3 V

v_(Red) =v_(cc) -v_(CE-sat) -v_(Red LED) =-5-(-0.075)-(-1.85)=-3.075 V

v_(Green) =v_(cc) -v_(CE-sat) -v_(Green LED) =-5-(-0.075)-(-3)=-1.925 V

v_(Blue) =v_(cc) -v_(CE-sat) -v_(Blue LED) =-5-(-0.075)-(-3)=-1.925 V

If R_(bb) =82 kΩ (LED resistors calculation):

I_B =(v_(cc) -v_(BE))/(R_(bb))=(-5-(-0.7))/82000=-52.4 μA

I_C =I_B h_(FE-min) =-5.24∙10^(-5) ∙180=-9.44 mA

R_(LED) =(v_(Resistor))/(I_C)

R_(Red) =(v_(Red))/(I_C)=(-3.075)/(-9.44∙10^(-3))=326 Ω

R_(Green) =(v_(Green))/(I_C)=(-1.925)/(-9.44∙10^(-3))=204 Ω

R_(Blue) =(v_(Blue))/(I_C)=(-1.925)/(-9.44∙10^(-3))=204 Ω

If I_C =30 mA (Room 1 & Room 2 Base resistor calculation):

I_B =(I_C)/(h_(FE-min))= -0.03/180= -1/6000A=166.67 μA

R_(bb) =(v_(cc) -v_(BE))/(I_B)=(-5-(-0.7))/(-1/6000)=25.8 kΩ

## 8.7 Pinout

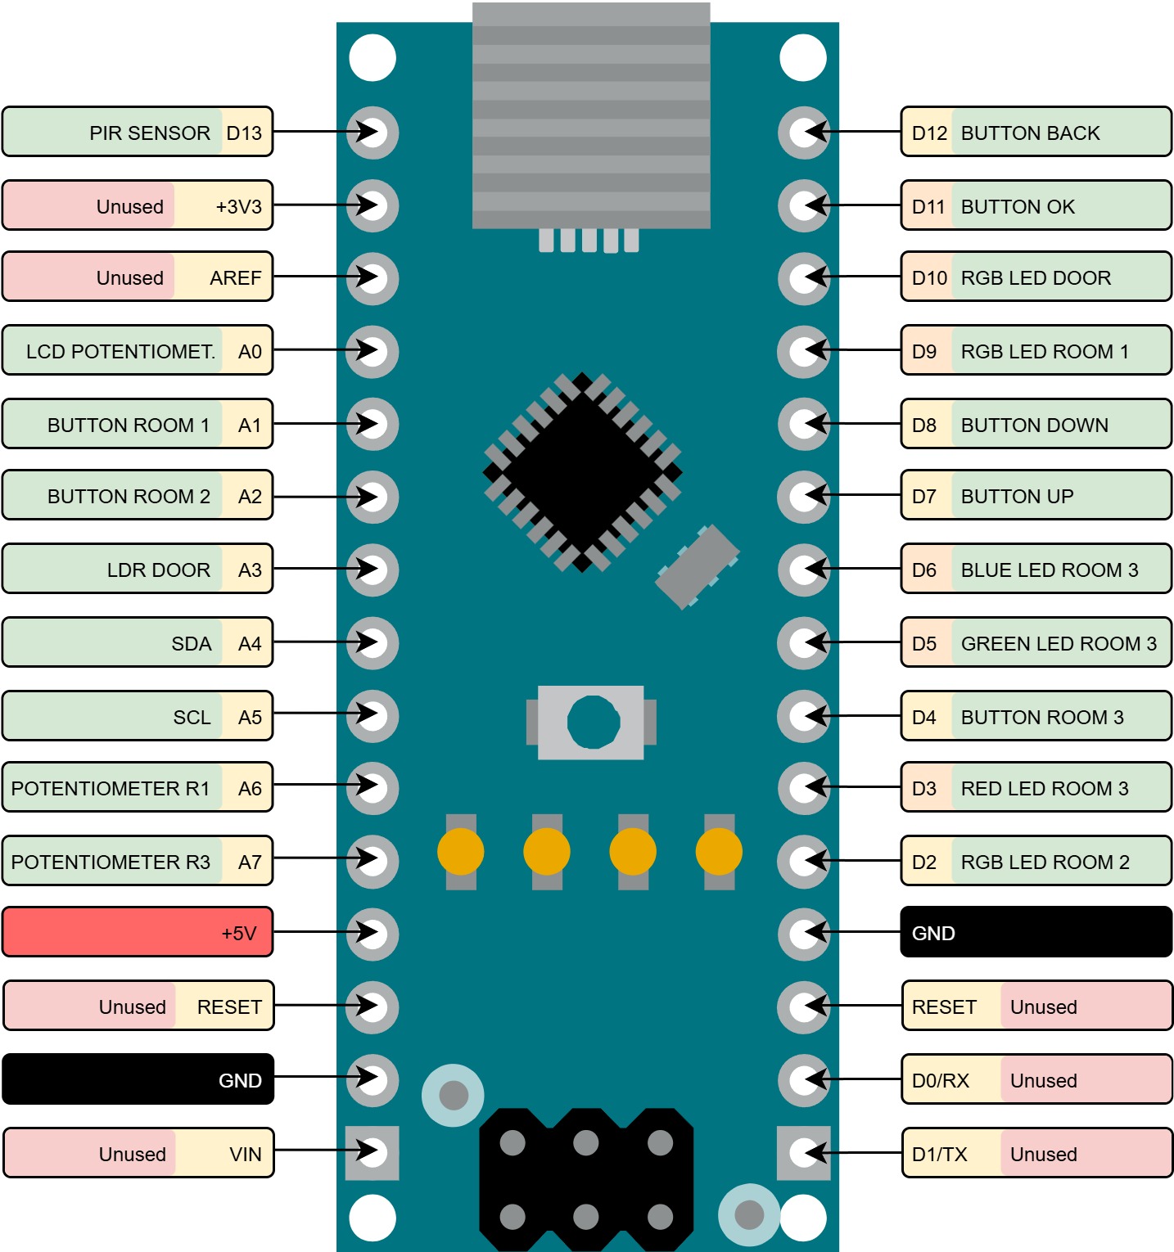
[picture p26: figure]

## 8.8 Wiring table for pin header connectors

Wire Color | Component / Pin | Microcontroller pin | Pin Header Connector
Blue | LED Room 1 / GND | GND | J9 / 4.
Red | LED Room 1 / Red | D9 | J9 / 1.
Blue | LED Room 2 / GND | GND | J10 / 4.
Red | LED Room 2 / Red | D2 | J10 / 1.
Blue | LED Room 3 / GND | GND | J11 / 4.
Red | LED Room 3 / Red | D3 | J11 / 1.
Green | LED Room 3 / Green | D5 | J11 / 2.
Orange | LED Room 3 / Blue | D6 | J11 / 3.
Yellow | Button Room 2 / 1. | A2 | J5 / 2.
Yellow | Button Room 2 / 1. GND | GND | J13 / 3.
Black | Button Room 2 / 2. GND | GND | J13 / 4.
Brown | Button Room 3 | D4 | J3 / 1. + 2.
Gray | LDR | A3 | J8 / 1. + 2.
Yellow | Pot Room 1 / 2. | A6 | J4 / 1.
Orange | Button Room 1 / 1. | A1 | J6 / 2.
Orange | Button Room 1 / GND | GND | J4 / 2.
Yellow | Pot Room 3 / 2. | A7 | J7 / 2.
Blue | Pot Room 3 / GND | GND | J7 / 3.
Blue | LED Door / GND | GND | J12 / 4.
Red | LED Door / Red | D10 | J12 / 1.
Blue | PIR / GND | GND | J1 / 3.
Green | PIR / 5V | 5V | J1 / 1.

## 8.9 Wiring table for connecting Control panel to main PCB

Function | Wire Color | Connector on Control Panel PCB | Connector on Main PCB | Microcontroller Pin
Control panel pot | White | 1 | 10 | Not implemented
Button Down | Gray | 7 | 9 | D8
Button ok | Green | 6 | 8 | D11
Button up | Purple | 5 | 7 | D7
Button back | Black | 3 | 6 | D12
GND | Blue | 8 | 5 | GND
5V | Red | 2 | 4 | 5V
LCD SDA | Brown | 10 | 3 | A4
LCD SCL | Orange | 9 | 2 | A5
Button sleep | | 4 | 1 | D0/RX (Not connected or used)

## 8.10 Project budget

### 8.10.1 Budget table

Component | Quantity | Price/piece [dk]* | Price of components [dk]*
PIR sensor | 2 | 112,66 | 225,32
LED RGB | 10 | 18,522 | 185,22
Buttons | 20 | 0,814 | 16,28
Arduino Nano every | 1 | 111,44 | 111,44
Potentiometer | 5 | 21,04 | 105,2
9V Battery | 1 | 107,15 | 107,15
Battery connector | 2 | 6,64 | 13,28
Total sum | | | 763,89

*Including VAT

### 8.10.2 Datasheets of the ordered components

Component | Datasheet
PIR sensor | https://docs.rs-online.com/eb35/0900766b81644fd0.pdf
LED RGB | https://docs.rs-online.com/ad97/0900766b8139d70b.pdf
Buttons | https://docs.rs-online.com/e4fd/A700000009237051.pdf
Arduino Nano every | https://docs.rs-online.com/1d66/A700000006519064.pdf
Potentiometer | https://docs.rs-online.com/ce7e/0900766b80fa5779.pdf
9V Battery | https://docs.rs-online.com/c3bb/A700000007739750.pdf
Battery connector | https://docs.rs-online.com/3822/A700000006711332.pdf

## 8.11 Contributions

Task | Main contribution | Side contribution
Component ordering | Jakub | -
Room 1 KiCad schematic | Roko | -
Room 2 KiCad schematic | Milan | -
Room 3 KiCad schematic | Jakub | -
Door KiCad schematic | Katharina | Milan, Roko, Jakub
Control panel schematic | Katharina
Whole KiCad schematic | Milan | -
3D model design - Walls | Milan | -
3D model design - Floor | Katharina | -
3D model design - Potentiometer casing | Roko | -
3D model design - Button casing | Jakub | -
3D model design - PCB cover | Jakub | -
Control panel PCB (design + soldering) | Jakub | -
Main PCB (design + soldering) | Katharina | -
Wire soldering | Katharina | Jakub
Room 1 code | Milan | Roko
Room 2 code | Milan | -
Room 3 code | Jakub | -
Control panel code | Milan | Jakub
Door code | Milan | -
Putting the prototype together | Katharina + Jakub | -
Structure of the report | Danylo | -
Report writing - Abstract | Milan | -
Report writing - Introduction | Jakub | -
Report writing - Methods (Hardware) | Katharina | -
Report writing - Methods (Software) | Milan | -
Report writing - Results | Milan | -
Report writing - Discussion | Jakub | -
Report writing - Conclusion | Jakub | -

Smart home model, University of Southern DenmarkJanuary 1, 2025

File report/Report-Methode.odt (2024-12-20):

Semester Project Report

Methodes

Circuit design

We choose to have a Control panel, because a characteristic of a smart home is, that the lighting can be controlled from outside the home. The control panel could be developed further to be wireless with Bluetooth and controlled via an app.

For the Control panel, we choose to use buttons to navigate in the menu displayed on the LCD.

A Potentiometer was planed to control the RGB Values and the brightness of the LED's.

We incorporated 5 buttons UP, DOWN, OK, BACK and a Button for an extra function (sleep mode).

The Resistors are Pull down Resistors for the I2C Module of the LCD.

3D-Modelling

Worked on a 3D-Modell for the House to 3D-print. Decided to print the Bottom and laser cut the Walls, because the Walls have a simpler design.

PCB

We decided to have the components in the house (switch-buttons, LED, Potentiometer) wire connected to the PCB with pinheader connectors. So the PCB is detachable from the House.

We Further divided the circuit in two PCB. One for the Control panel, with the Buttons and Potentiometer mounted on the PCB via Through hole soldering and a pinheader connection to the Liquid Crystal Display (LCD).

The other PCB has the transistor driver circuit for the LED's and the microcontroller on It.

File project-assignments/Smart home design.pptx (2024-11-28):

## Smart home design


Group 7

## Summary

- 3d models and schematics
- Software
- Expectations and conclusion

## 3d models and schematics

- Kicad
- Fusion 360
- Everyone had their own part

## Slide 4


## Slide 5


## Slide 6


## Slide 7


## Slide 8


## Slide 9


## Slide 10


## Software

- Visual studio
- C programming language

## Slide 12


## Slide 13


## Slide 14


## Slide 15


## Expectations and conclusion

- Fully functional before the given deadline
- Light status can be changed from control panel
- Outside light should turn on when detecting movement
- Continuing work on software
- Design of the casing for the main control panel
- Debugging and fine tunning

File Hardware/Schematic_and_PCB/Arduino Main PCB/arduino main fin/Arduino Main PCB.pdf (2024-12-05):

Tabelle1

Reference
A1
C1,C2,C3,C4,C10
C5,C6,C7,C8,C9
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
Q1,Q2,Q3,Q4,Q5,Q6
R1,R8,R9,R10,R23,R24
R2,R3,R4
R5,R6,R7
R11,R14,R17,R20
R12,R13,R15,R16,R18,R19,R21,R22
R25
TP1,TP2,TP3,TP4,TP5,TP6,TP7,TP8,TP9,TP10,TP11,TP12,TP13,TP14,TP15,TP16,TP17

Tabelle1

Value | DNP
1
4.7mu | 5
100n | 5
D | 1
PIR_sensor | 1
Control_Panel | 1
Buttons_Room_3 | 1
Buttons_Room_1 | 1
Pot_Room_3.1 | 1
Pot_Room_1 | 1
Pot_Room_3.2 | 1
LDR_Door | 1
LED_Room_1 | 1
LED_Room_2 | 1
LED_Room_3 | 1
LED_DOOR | 1
Buttons_Room_2 | 1
Barrel_Jack | 1
Power | switch | 1
BC557 | 6
0 | 6
82k | 3
27k | 3
330 | 4
220 | 8
80 | 1
| 17

Qty
Arduino_Nano_Every

TestPoint

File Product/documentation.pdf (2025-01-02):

# Smart home model

Authors:

Milan Caban

Jakub Dubrava

Katharina Lea Johannsen

Roko Grgic

Danylo Lysechko

Yumna Ayesha

Smart home model, University of Southern Denmark | January 1, 2025

## 1 Abstract

This semester’s project focused on designing and building a functional smart home model equipped with a centralized control panel for managing room-specific features such as lighting and PIR sensor. The model demonstrates how modern technology can enhance convenience, energy efficiency, and user interaction within residential spaces. Since this is a first experience with electronic product design for most of the members, we expect that this journey will teach us a lot about electronics and teamwork.

## Table of Contents

## Table of Figures

## 2 Introduction

This report encompasses various procedures involved in construction of a smart home model. One of the initial definitions of smart home is provided by Lutolf, defining it as “an integration of different services within a home by using a common communication system.” Moreover, it should assure „an economic, secure, and comfortable operation of the home and include a high degree of intelligent functionality and flexibility.” (Lutolf, 1992) A fresher definition by Satpathy states, that “a home which is smart enough to assist the inhabitants to live independently and comfortably with the help of technology is termed as smart home. In a smart home, all the mechanical and digital devices are interconnected to form a network, which can communicate with each other and with the user to create an interactive space.” (Satpathy, 2006) We consider this definition more proper, as it emphasizes the role of network in smart home systems, in contrast to the vaguer term ‘common communication system’ used by Lutolf.

According to Zielonka, one of the major development trends related to smart homes are healthcare and quality of life, security in data management and optimal energy management and sustainability. Presumably, the trend of energy management and sustainability is intertwined with recently rising ecological trend (Zielonka, et al., 2021). However, the graph in Figure 1 shows that advanced lighting and intelligent energy management are not amongst the most influential trends. Nevertheless, the upcoming paragraph underlines the significance of innovation in this sector.


Figure 1 Graph of Leading Smart Home Innovation Trends Worldwide in 2023

The use of LEDs as an illumination component is crucial not only for lower energy consumption in comparison to conventional lightning bulbs. According to Schratz, “when compared to incumbent lighting technologies, most LED fixtures deliver at least a 50% improvement in energy savings, which translates directly into significantly lower carbon emissions and a much smaller environmental impact”, while they offer more advantages such as “less heat output, lower risk of ignition due to dust and particle accumulation, improved color rendering for a better quality of light, and negligible UV light output, which reduces insect infestation and product deterioration”. Remarkably, its life-span can reach “more than 100,000 operating hours”. (Schratz, Christine, Struhs, & Gray, 2016)

Although lights with movement sensors are commonly used nowadays, they could benefit from integration into a centralized system, bringing everything ‘under one roof’. The main advantage of a system with a centralized unit is its flexibility, as users would be able to manipulate light status manually inside the house as well as through communication with the centralized unit, for instance via a control panel. New features could be implemented, for example allowing the change of various thresholds according to user’s needs easily and any time.

However, many challenges emerged during the design process. The most significant problems can be summarized in several ‘how to’ questions:

1. How to construct the house?
2. How to adjust the intensity or color of the light?
3. How to assemble and integrate the circuits?
4. How to structure the control panel menu?

Mentioned questions are answered in subsequent 8 sections. The third chapter includes detailed steps of the design process, where any decision is complemented by justification. The fourth section concerns the final product, possibly deviating from the planned design. The fifth section contains comparison of design and result as well as technical limitations. Moreover, the sixth section provides a concise conclusion on the whole project. References and appendices are placed in the last two sections.

## 3 Methods

## 3.1 Circuit design

### 3.1.1 Control panel PCB

We chose to have a Control panel, because according to Alam, a characteristic of a smart home is that it can be controlled remotely from outside the home. (Alam, Reaz, & Ali, 2012) The control panel could be developed further to be wireless with Bluetooth and controlled via an app.

For the Control panel, we chose to use buttons to navigate in a menu displayed on the LCD.

A Potentiometer was planned to control the RGB Values and the brightness of the LEDs.

We incorporated 5 buttons UP, DOWN, OK, BACK and a Button for an extra function (sleep mode).

The 4k7 Ω Resistors function as Pull up Resistors for the I2C Module of the LCD.


Figure 2 Control panel PCB 3D model

### 3.1.2 Main PCB

We decided to have the components in and on the house (switch-buttons, LED, Potentiometer, Sensors) connected to the PCB with pin header connectors. So, the PCB is detachable from the House. We Further divided the circuit in two PCB’s. One for the Control panel, with the Buttons and Potentiometer mounted on the PCB via Through hole soldering and a pin header connection to the Liquid Crystal Display (LCD).

The other PCB has the transistor driver circuit for the LED's, circuits for the Sensors and the microcontroller on It.


Figure 3 Main PCB 3D model

## 3.2 3D-Modelling

The design of the house can be divided into two categories, one is base and the other are walls and floor.

The base was designed in Fusion 360 for 3D printer. The whole model consists of 230mm X 230mm square with three rooms. We also added mounting holes for walls and floor and space under the floor is empty for routing cables, for that reason we also added openings at the back near the control panel.


Figure 4 Base 3D model

Walls and floor were designed in Fusion 360 as well, but they were designed for a laser cutter. After laser cutting some parts had to be treated using a rasp so they fit together, because some connections are angled 45 degrees for stronger fit.


Figure 5 Walls and floor model

For slicing we used Bambu Studio and printed it as well with a Bambu 3D printer.

## 3.3 Assembly of the Model

After receiving the drilled PCBs, we checked the connections with a multimeter.

Because the PCBs had no connection errors, we continued with the next step: soldering the PCBs.

To have more space underneath the PCB when placing it on the table, we first soldered some of the pin headers to make it stand stable while soldering the vias.

Then we soldered the components starting with the flattest and ending with the tallest.

We reused the female-to-female jumper cables to create the wiring to the components in the house. So, the cables were cut in half and soldered to flex wire around 475 mm in length. Then the flex wires were soldered to the components according to the color-coded wiring table. We used shrinkable tubes to isolate the soldered wire to prevent short circuits. Now with the wiring the entire system and code could be tested.

The Control Panel PCB was mounted with four M3 x 40 mm screws and 20 mm long spacers on to the Mainboard.

Where the LEDs should go, 5mm holes got drilled in the walls for the Lens to go through. To mount the LDR sensor and the PIR sensor, holes were drilled in the outer walls as well.

To arrange the LEDs, buttons and sensors in the house, it was marked where the wires go through the floor. According to that, the floor plates got holes drilled through the wood.

With the components placed on the walls, the female connectors were thread through the holes in the floor, routed at the bottom and lead to the casing of the Control Panel.

The LCD was mounted to the lid of the control panel casing with four M3 x 10 mm screws and nuts.

With all the connections according to the wiring table, the casing of the control panel could be closed and the walls screwed to the bottom with four 3.5 x 25 mm spax screws. To fix the wires on the walls we used electrical tape.

## 3.4 Problems during assembly

On the Main PCB connection issues and other connection issues were discovered while testing the connections with a multimeter. We fixed the problem with resoldering the visual faulty solder joints.

We realized that D0 was just connected on top layer on the Main PCB Layout, a via was forgotten to be placed in front. Fortunately, it was not relevant for the main functionality because it was meant to be for an optional button to start an extra function.

The Wire for Room 1 Button was swapped with Room 1 Pot, because the IO Pin A6 formerly assigned to Room 1 Button can only be used analog.

The Potentiometer on the control panel was not implemented because it was more convenient to code the user interface only with buttons.

The Pin D1/RX was not able to be used because it interfered with serial communication (RX/TX), even without being connected to a PC. That was probably caused by the USB C connector circuit on the microcontroller. D1 was originally used for button room 2 but then changed to A2. Because J5 had just one pin connected to A2, the two wires of the buttons in parallel were soldered to one female connector.

## 3.5 Introduction to software

Our first idea was to create a library for every room, door and control panel. The library should implement “Init()” and “Update()” functions which will be called in main function. In addition to them, we also implemented some functions which control the state of the room directly, for example they turn the light on and off. This approach made code more maintainable and readable, therefore we used it in our final build. Also, we could very easily divide individual code parts to team members, in our case everyone had to program one room.

Figure 6 Main program

We had to come up with a solution to how buttons should operate in rooms where there is the possibility to change brightness or color of the light. After a few discussions we stuck to the idea that the last action takes effect. This means that if brightness was set to half of its potential by clicking the button the light is turned off (light is set to maximum brightness after clicking button, only when brightness is zero), even though the potentiometer’s value stays unchanged. This solution turned out to be very handy when we started working on the control panel.


Figure 7 Software diagram

When a button is pressed the change from not being pressed and being pressed isn’t immediate, there are always some fluctuations which are the result of mechanical construction of a button. We solved this issue by adding delay every time a button is pressed, this resulted in functions for every button which check status of a button and if it is pressed, they start a 100 ms delay.


Figure 8 Check button function

## 3.6 Room 1 software

Room 1 has one button for turning the LED on and off and one potentiometer for controlling the brightness of the LED. We implemented functions for controlling and retrieving information about the LED’s status and brightness.


Figure 9 Room1.h

In “Init()” we initialized ADC and PWM using Alin’s libraries and set button pin as input with pull up resistor. To do that we referred to AtMega datasheet (Atmel Corporation, 2015) and Arduino Nano pinout (Arduino cc, 2021). We used these documents for other rooms and control panel as well.

“Update()” function checks if potentiometer values changed since last measurement, if yes update LED’s intensity accordingly. Then it checks if button is pressed and wasn’t pressed previously, if this statement is true then the status of LED is inverted.


Figure 10 Update room 1 function

## 3.7 Room 2 software

This is the simplest room, it has only two buttons and one LED. Since we wired buttons in parallel, from the Arduino perspective they act as a one button. Again, we added functions for getting and setting status of the LED. Logic in “Update()” and ”Init()” is very similar to Room 1, just without potentiometer and LED is controlled using registers not using the PWM library.


Figure 11 Update room 2 function

## 3.8 Room 3 software

Room 3 contains one potentiometer for color changing, a button and one LED. We decided that potentiometer will affect only one property of the light, for example red or green.

We were aware of the limitations of this approach and decided to implement configuration of a potentiometer’s-controlled value into control panel, in final version it is possible to choose which part of the light’s color is controlled by a potentiometer. We also added HSV (Atkins, 2010) color model because it is much easier to work with for people. So, you can configure red, green, blue, hue, saturation, value whilst hue is default.


Figure 12 Room3.h

The potentiometer is read the same way as in the room 2 and LED is controlled using PWM 3 from Alin’s library, turning on and off using the switches between full white and completely off.

## 3.9 Door software

Door’s LED is controlled by PIR sensor and LDR, therefore there is no button. In addition to “Init()” and “Update()” functions we implemented functions for detecting movement, getting current value of LDR and setting threshold for LDR.

In “Init()” function we just initialized ADC using Alin’s libraries and pin for LED as output and pin for PIR sensor as input using registers.

Every time the movement is detected and LDR has higher value than threshold, LED is turned on and timer is reset. Timer is just one variable which is incremented by one every time the “Update()” function is called, when the LED is turned on the variable is set to zero, when this variable reaches particular value LED is turned off.


Figure 13 Update door function

## 3.10 Control panel software

Even though it is not a room, it works very similarly to one, because buttons function the same as in the rooms and control panel and background logic is just a more complicated version of a LED.


Figure 14 Init control panel function

In addition to physical components, which make up control panel, we had to implement back-end logic for the menu responsible for storing and navigating in menu elements, we also implemented some type of a link or connection between control panel and rooms, we called it mediator.


Figure 15 Part of the update control panel function

Mediator’s responsibilities are to retrieve and change information for room associated with menu element, for example for element showing status of LED in room 1, mediator will return status of led in room 1 and element will be updated, when value in menu element is changed mediator ensures that room is updated as well.

### 3.10.1 Menu implementation

When we were designing a menu, we took inspiration from files and folders in a computer, every element in a menu can be file or folder.

Folder contains more folders or files, for example at the top level of the menu there are four folders (room 1, room 2, room 3, door) after selecting one of the folders its content will be displayed on control panel. Returning to a previous folder is done by clicking “back” button.

Files hold values which can be linked to room, or it can be some arbitrary value which affects other files for example file “Color format” can have value “RGB” or “HSV” (Atkins, 2010) and this value affect how is color of the light in room 3 represented on control panel. After selecting file its value can be changed by clicking “up” and “down” buttons, changes take effect instantaneously. File can be deselected by clicking “back” button.

Files and Folders are contained in “Menu_element” struct (W3Schools, C structs, n.d.) this struct has a variable of enumeration type (W3Schools, C enums, n.d.) to determine if current menu element is file or folder, after this variable is union (TutorialsPoint, n.d.) with file or folder struct in it. The only differences between folder and file structure are that file has also value, type of data stored in it and variable which determines if it is selected.


Figure 16 Menu structs

Our first idea for storing menu elements was to use multidimensional array, but we quickly realized that it would be difficult to work with it, because we can’t determine the size of an array in C, and we risk going out of bounds of it. For that reason, we stored all the elements in one dimensional array and location of the element we encoded in its “ID”.

ID acts as a path to the element for example after clicking second folder on first level first element on second level will have ID equals to 12, path is inverted (first level is last digit and last level is first digit) so it is easier to search in array of elements.


Figure 17 Menu diagram

### 3.10.2 Display implementation

To simplify the use of display we created helper library, which has functions for updating whole display with menu elements, which are passed to the function as a parameter, and for updating one element, so display is not refreshed every time a value in one element is changed only that element is refreshed.


Figure 18 Display.h

I addition to displaying current menu elements, display also mark hovered element with “*” character and selected element with “>” character.

### 3.10.3 Mediator implementation

As it was mentioned in previous chapters, to update rooms using control panel we are using Mediator. Mediator’s API consists of two functions which return pointer to a function one returns a function for changing value and the second one returns a function for getting a value. Which function to return is determined by menu element ID, functions aren’t stored in an array, pointer to a particular function is returned using switch statement (W3Schools, C switch, n.d.) which switches between different IDs.


Figure 19 Mediator.h


Figure 20 get_getter_func function

## 3.11 Software problems

When debugging the whole assembly we encountered some issues, those problems were mostly logical and easily fixable. However, we couldn't fix problems with altering the color of light in room 3 using control panel when color format was set to HSV (Atkins, 2010), therefore this feature is not available and can be changed using control panel only when color format is set to RGB.

Another inconvenience which made its way to the final product is unreliable control of the status of light in door, which means that door light can be controlled by control panel, but it does not work every time, we couldn’t figure out why it happens.

## 4 Results

In hindsight we can say that the project went well, even though we found ourselves in a hurry at the end, due to unexpected problems and difficulties.
Our main focus when designing smart home was on connectivity and ease of controlling individual rooms. We achieved this by incorporating a control panel whilst perceiving ability to control rooms in place. When working on the control panel we focused on making it as intuitive as possible, therefore we used the approach the last action takes effect. This way you don’t have to worry whether the light in a room is turned on or off because you can always set it in a room or in the control panel.
When designing the hardware part of the project we thought about how to route cables a lot, we wanted simple solution, which allows us to make mistakes when routing in terms of length of cables. By making the floor hollow we were able to route all the cables easily while having space for very long cables. Since all the cables are in the floor, we were able to use a laser cutter to cut walls which was a faster and easier way to manufacture walls.
When it came to software, we didn’t want to write everything in one file and somehow make it work, because this way the code would become unreadable very quickly and possible problems would be very difficult to solve. Therefore, we created a library for every room and in the main function we just initialized and updated the room. In addition to room libraries, we created some helper libraries for the menu, display and mediator. As a result, we had a very clean and maintainable code base, which made it much easier to find and fix bugs.

## 5 Discussion

This section contains explained differences between results and design, limitation of the project and suggestions for further development.

## 5.1 Design and results comparison

Overall, the design functioned as expected. Nevertheless, some features had to be abandoned, as their functionality was not required. Notably, the use of RX/TX or D0/D1 pins turned out to be complicated. Their behavior is different in comparison to standard digital pins, which was found out later in the project. Therefore, they are not used in the final version of the project. In addition, the button for additional features, initially intended as a switch to turn on or off sleep mechanism, could not have been implemented due to a design flaw. It is described in section 3.4 Problems during assembly.

What’s more, it was decided that the control panel potentiometer will not be used. It was intended as a tool to change brightness or color component directly on the control panel, however, such implementation proved to be more complex than the implementation of this function to the control panel buttons. Another neglected feature is the ability to change color components in HSV format, in Room 3 via the control panel. Presumably, the adjustment of the color values was faulty due to unknown causes likely stemming from coding errors. The displayed format of the color in Room 3 menu can still be changed, but the ability to adjust color values through control panel is solely available in RGB format.

## 5.2 Technical limitations

Moreover, some of our decisions were not optimal due to a few restrictions. One of the restrictions were mandatory requirements of the project, namely the use of Arduino Nano microcontroller and LCD display provided by the SDU. However, these requirements weren’t and shouldn’t be considered as true restrictions within the context of the project. The aim of this remark is to acknowledge these requirements, as they fundamentally influenced the development process. In addition, other confinements were introduced by electrical component provider and PCB manufacturer. The choice of electrical components was restricted by the limited variety of component models sold by the provider, while the design of PCBs had to align with available services of PCB manufacturer.

## 5.3 Retrospective

Furthermore, the dynamic of a newly formed project group affected the whole development process. The project plan design was unrealistic, as the capabilities of the members didn’t match the task skill/knowledge requirements most of the time as well as the pace proposed by the plan was too high. However, due to the high frequency of group meetings, there was consistent work done each week and any problems could be resolved quicker. Arguably, a thorough plan was not required to efficiently finish the project due to a few factors. For example, members were new to the concept of working in group on such a technical project, members weren’t familiar with all the aspects of the development process, but most importantly, cumulative acquisition of knowledge didn’t allow smoother completion of tasks during the whole semester. Nevertheless, a group would benefit from more frequent assignment of deadlines to the tasks emerging during the meetings. Notably, this section is not objective and is written from the writer’s perspective. The opinions of other members on this topic might significantly differ.

## 5.4 Discussion conclusion

To conclude, a couple of insignificant features included in the design weren’t implemented due to various reasons. Various sources of technical limitations were mentioned. The group dynamic is brought up as a factor influencing the development process, while the requirement of a strict project plan is challenged.

## 6 Conclusion

In conclusion, the finished prototype satisfies all requirements. Regarding materials used for the construction of the model, medium-density fiberboard (MDF) can be used as a material for models due to its low manufacture time and high customizability, while polylactic acid (PLA) is more suitable material for more complex shapes like threads thanks to the 3D printing.

Moreover, PWM can be utilized for adjustment of color or brightness of LED, while transistor can be used as switches and amplifiers of current. Printed circuit boards (PCB) are a practical option for placing circuitry, while capacitors are able to reduce signal distortion.

Higher readability of code and easier assignment of coding tasks can be achieved by having multiple libraries each for different sections of smart home. In addition, computer file organization served as essential inspiration during the development of a menu structure.

High frequency of group meetings contributed to consistent progress. However, sensible deadlines could potentially enhance workflow in the group.

What’s more, members are now familiar with the development of a technical project encompassing various aspects, while acquiring new knowledge and skills. Amongst newly acquired skills are: 3D design, circuit design, improved soldering, improved coding abilities and many more.

All in all, the project greatly contributed to the evolvement of members’ hard and soft skills, while it familiarized them with the dynamic in a project group. The contributions of each member are shown in a table in Appendix 8.12.

## 7 References

Alam, M. R., Reaz, M. B., & Ali, M. A. (2012). A Review of Smart Homes—Past, Present, and Future. IEEE.

Arduino cc. (2021). Arduino Nano pinout. Arduino cc.

Atkins, | R. | (2010, | December). | RGBConverter. | Retrieved | from | GitHub:
https://github.com/ratkins/RGBConverter

Atmel Corporation. (2015). ATmega328P datasheet. San Jose: Atmel Corporation.

Lutolf, R. (1992). Smart Home concept and the integration of energy meters into a home based system. Seventh International Conference on Metering Apparatus and Tariffs for Electricity Supply 1992 (pp. 277-278). Glasgow: IET.

Satpathy, L. (2006, 5 8). Smart Housing: Technology to Aid Aging in Place - New Opportunities
and | Challenges. | Retrieved | from | Thesis | and | Dissertations:
https://scholarsjunction.msstate.edu/td/3967/

Schratz, M., Christine, G., Struhs, T. J., & Gray, K. (2016). A New Way to See the Light: Improving Light Quality with Cost-Effective LED Technology. IEEE Industry Applications Magazine, 55-62.

TutorialsPoint. | (n.d.). | C | unions. | Retrieved | from | TutorialsPoint:
https://www.tutorialspoint.com/cprogramming/c_unions.htm
W3Schools. | (n.d.). | C | enums. | Retrieved | from | W3Schools:
https://www.w3schools.com/c/c_enums.php
W3Schools. | (n.d.). | C | structs. | Retrieved | from | W3Schools:
https://www.w3schools.com/c/c_structs.php
W3Schools. | (n.d.). | C | switch. | Retrieved | from | W3Schools:
https://www.w3schools.com/c/c_switch.php

Zielonka, A., Woźniak, M., Garg, S., Kaddoum, G., Piran, J., & Ghulam, M. (2021). Smart Homes: How Much Will They Support Us? A Research on Recent Trends and Advances. IEEE Access, 26388-26419.

## 8 Appendices

## 8.1 Main PCB


## 8.2 Main board schematic


Control panel PCB

## 8.3 Control panel board schematic


## 8.4 Base drawing


## 8.5 Button casing drawing

## 8.6 Calculations

If Ic = −10 mA (Room 3 Base resistor calculation):

vCE−sat = −75 mV

ℎFE−min = 180

IB =

IC

ℎFE−min

= −

0.01
180 = −55 μA

Rbb =

vcc − vBE
IB

=

−5 − (−0.7)
−5.5 ∙ 10⁻⁵ = 78.2 kΩ

vResistor = vcc − vCE−sat − vLED

vRed LED = −1.85 V

vGreen LED = −3 V

vBlue LED = −3 V

vRed = vcc − vCE−sat − vRed LED = −5 − (−0.075) − (−1.85) = −3.075 V

vGreen = vcc − vCE−sat − vGreen LED = −5 − (−0.075) − (−3) = −1.925 V

vBlue = vcc − vCE−sat − vBlue LED = −5 − (−0.075) − (−3) = −1.925 V If Rbb = 82 kΩ (LED resistors calculation):

IB =

vcc − vBE

Rbb

=

−5 − (−0.7)
82000 | = −52.4 μA
IC = IBℎFE−min = −5.24 ∙ 10⁻⁵ | ∙ 180 = −9.44 mA

RLED =

vResistor
IC

RRed =

vRed
IC

=

−3.075
−9.44 ∙ 10⁻³ = 326 Ω

RGreen =

vGreen
IC

=

−1.925
−9.44 ∙ 10⁻³ = 204 Ω

RBlue =

vBlue
IC

=

−1.925
−9.44 ∙ 10⁻³ = 204 Ω

If IC = 30 mA (Room 1 & Room 2 Base resistor calculation):

IB =

IC

ℎFE−min

= −

0.03
180 = −

1
6000 A = 166.67 μA

Rbb =

vcc − vBE
IB

=

−5 − (−0.7)

−

1
6000

= 25.8 kΩ

## 8.7 Pinout


## 8.8 Wiring table for pin header connectors

Wire Color | Component / Pin | Microcontroller pin | Pin Header Connector
Blue | LED Room 1 / GND | GND | J9 / 4.
Red | LED Room 1 / Red | D9 | J9 / 1.
Blue | LED Room 2 / GND | GND | J10 / 4.
Red | LED Room 2 / Red | D2 | J10 / 1.
Blue | LED Room 3 / GND | GND | J11 / 4.
Red | LED Room 3 / Red | D3 | J11 / 1.
Green | LED Room 3 / Green | D5 | J11 / 2.
Orange | LED Room 3 / Blue | D6 | J11 / 3.
Yellow | Button Room 2 / 1. | A2 | J5 / 2.
Yellow | Button Room 2 / 1. GND | GND | J13 / 3.
Black | Button Room 2 / 2. GND | GND | J13 / 4.
Brown | Button Room 3 | D4 | J3 / 1. + 2.
Gray | LDR | A3 | J8 / 1. + 2.
Yellow | Pot Room 1 / 2. | A6 | J4 / 1.
Orange | Button Room 1 / 1. | A1 | J6 / 2.
Orange | Button Room 1 / GND | GND | J4 / 2.
Yellow | Pot Room 3 / 2. | A7 | J7 / 2.
Blue | Pot Room 3 / GND | GND | J7 / 3.
Blue | LED Door / GND | GND | J12 / 4.
Red | LED Door / Red | D10 | J12 / 1.
Blue | PIR / GND | GND | J1 / 3.
Green | PIR / 5V | 5V | J1 / 1.

## 8.9 Wiring table for connecting Control panel to main PCB

Function | Wire Color | Connector on Control Panel PCB | Connector on Main PCB | Microcontroller Pin
Control panel pot | White | 1 | 10 | Not implemented
Button Down | Gray | 7 | 9 | D8
Button ok | Green | 6 | 8 | D11
Button up | Purple | 5 | 7 | D7
Button back | Black | 3 | 6 | D12
GND | Blue | 8 | 5 | GND
5V | Red | 2 | 4 | 5V
LCD SDA | Brown | 10 | 3 | A4
LCD SCL | Orange | 9 | 2 | A5
Button sleep | | 4 | 1 | D0/RX (Not connected or used)

## 8.10 Project budget

8.10.1Budget table

Component | Quantity | Price/piece [dk]* | Price of components [dk]*
PIR sensor | 2 | 112,66 | 225,32
LED RGB | 10 | 18,522 | 185,22
Buttons | 20 | 0,814 | 16,28
Arduino Nano every | 1 | 111,44 | 111,44
Potentiometer | 5 | 21,04 | 105,2
9V Battery | 1 | 107,15 | 107,15
Battery connector | 2 | 6,64 | 13,28
Total sum | | | 763,89
*Including VAT

### 8.10.2 Datasheets of the ordered components

Component | Datasheet
PIR sensor | https://docs.rs-online.com/eb35/0900766b81644fd0.pdf
LED RGB | https://docs.rs-online.com/ad97/0900766b8139d70b.pdf
Buttons | https://docs.rs-online.com/e4fd/A700000009237051.pdf
Arduino Nano every | https://docs.rs-online.com/1d66/A700000006519064.pdf
Potentiometer | https://docs.rs-online.com/ce7e/0900766b80fa5779.pdf
9V Battery | https://docs.rs-online.com/c3bb/A700000007739750.pdf
Battery connector | https://docs.rs-online.com/3822/A700000006711332.pdf

## 8.11 Contributions

Task | Main contribution | Side contribution
Component ordering | Jakub | -
Room 1 KiCad schematic | Roko | -
Room 2 KiCad schematic | Milan | -
Room 3 KiCad schematic | Jakub | -
Door KiCad schematic | Katharina | Milan, Roko, Jakub
Control panel schematic | Katharina
Whole KiCad schematic | Milan | -
3D model design - Walls | Milan | -
3D model design - Floor | Katharina | -
3D model design - Potentiometer casing | Roko | -
3D model design - Button casing | Jakub | -
3D model design - PCB cover | Jakub | -
Control panel PCB (design + soldering) | Jakub | -
Main PCB (design + soldering) | Katharina | -
Wire soldering | Katharina | Jakub
Room 1 code | Milan | Roko
Room 2 code | Milan | -
Room 3 code | Jakub | -
Control panel code | Milan | Jakub
Door code | Milan | -
Putting the prototype together | Katharina + Jakub | -
Structure of the report | Danylo | -
Report writing - Abstract | Milan | -
Report writing - Introduction | Jakub | -
Report writing - Methods (Hardware) | Katharina | -
Report writing - Methods (Software) | Milan | -
Report writing - Results | Milan | -
Report writing - Discussion | Jakub | -
Report writing - Conclusion | Jakub | -

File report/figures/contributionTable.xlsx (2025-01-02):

Task | Main contribution | Side contribution
Component ordering | Jakub | -
Room 1 KiCad schematic | Roko | -
Room 2 KiCad schematic | Milan | -
Room 3 KiCad schematic | Jakub | -
Door KiCad schematic | Kati | Milan, Roko, Jakub
Whole KiCad schematic | Milan | -
3D model design - Walls | Milan | -
3D model design - Floor | Kati | -
3D model design - Potentiometer casing | Roko | -
3D model design - Button casing | Jakub | -
3D model design - PCB cover | Jakub | -
Control panel PCB (design+soldering) | Jakub | -
Main PCB (design+soldering) | Kati | -
Room 1 code | Milan | Roko
Room 2 code | Milan | -
Room 3 code | Jakub | -
Control panel code | Milan | Jakub
Door code | Milan | -
Putting the prototype together | Kati+Jakub | -
Structure of the report | Danylo | -
Report writing - Abstract | Milan | -
Report writing - Introduction | Jakub | -
Report writing - Methods (Hardware) | Kati | -
Report writing - Methods (Software) | Milan | -
Report writing - Results | Milan | -
Report writing - Discussion | Jakub | -
Report writing - Conclusion | Jakub | -

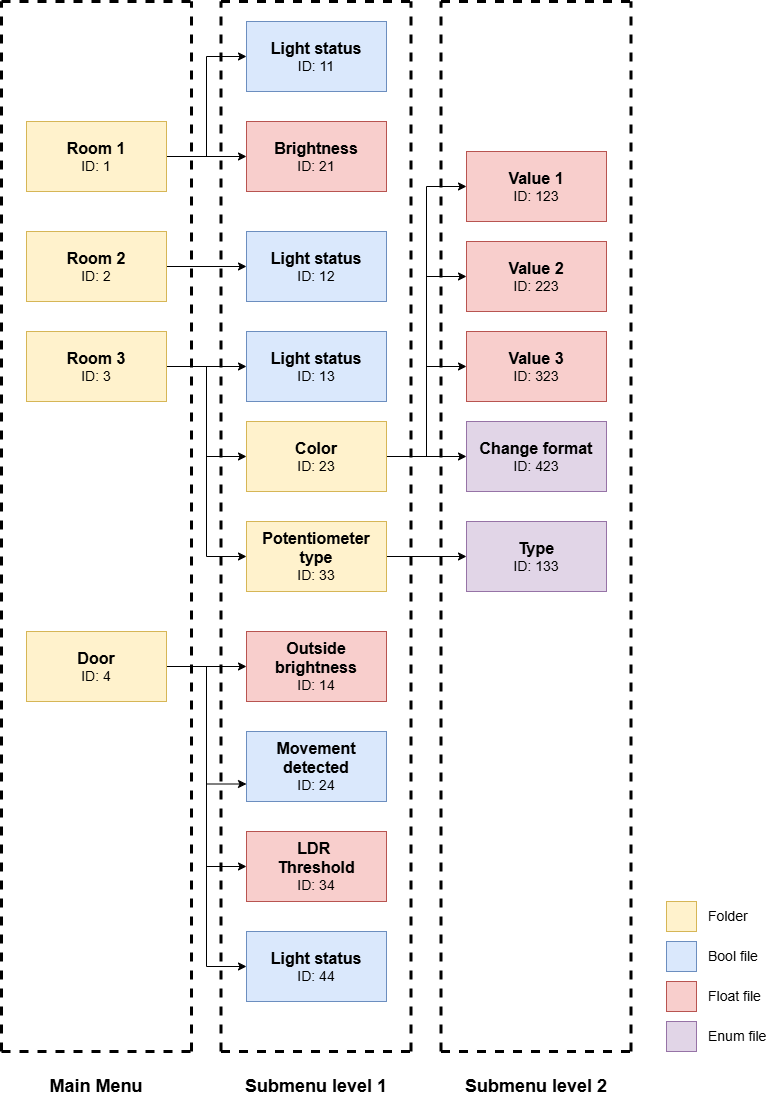
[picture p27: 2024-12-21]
report/figures/menu_structure.drawio.png

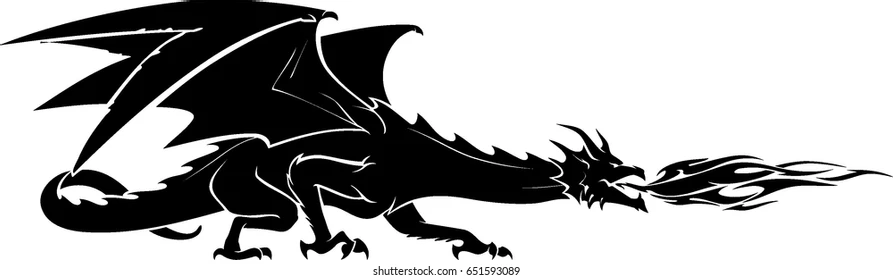
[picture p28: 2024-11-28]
Hardware/3D_model/Walls_model/dragon.webp

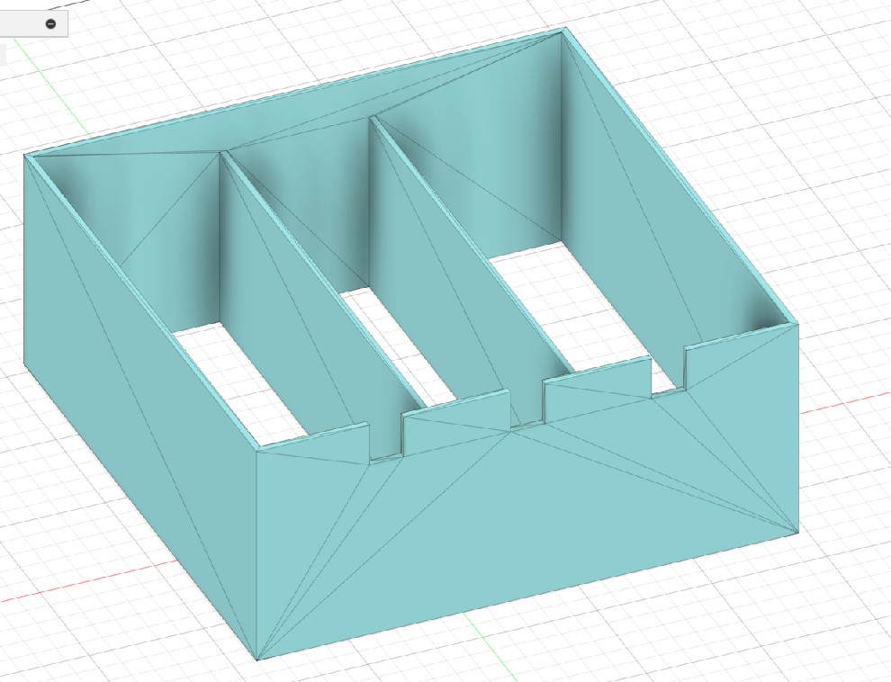
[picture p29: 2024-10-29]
Hardware/3D_model/Walls_model/walls.jpg

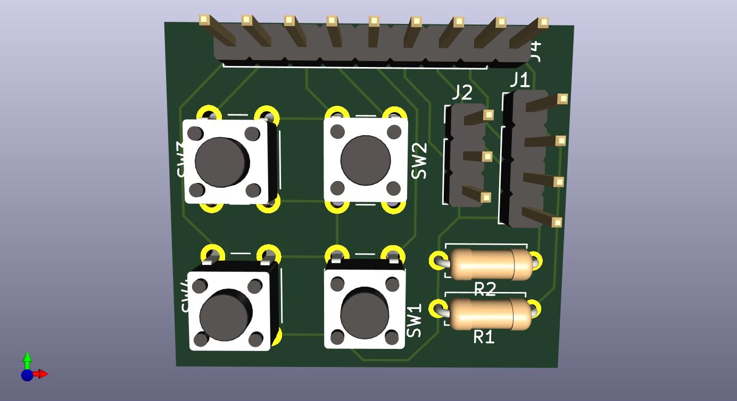
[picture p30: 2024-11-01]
Hardware/Schematic_and_PCB/LCD_PCB/LCD_PCB_V1.jpg

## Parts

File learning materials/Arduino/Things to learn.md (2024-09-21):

# Arduino thungs to learn

As we are learning C on embedded systems we will use it in our project as well. Arduino is usually programmed with C++, which is basically the same but has some more things.

You can learn C [here](https://www.w3schools.com/c/).

When working with Arduino it is very important to get familiar with this [document](../../datasheets/Atmel-7810-Automotive-Microcontrollers-ATmega328P_Datasheet.pdf), where you can find everything about chip on Arduino nano. If you think it is very long and not clear, then you will be delighted to hear that this is the simplest and best structured datasheet I had ever work with. You do not have read it all basic orientation in it.

Here is [video](https://www.youtube.com/watch?v=1EXXqWweTkI) about how to read datasheets.

You always learn by doing things, therefore there are some websites with Arduino projects or simulations.

[Wokwi](https://wokwi.com/arduino) - Website for simulating circuits with Arduino and Arduino itself.

[Tinkercad](https://www.tinkercad.com/dashboard) - This website can do much more than 3D modeling.

[Instructables](https://www.instructables.com/Arduino-Projects/) - Website with projects for Arduino.

[Arduino projects](https://projecthub.arduino.cc/) - Official Arduino website with projects.

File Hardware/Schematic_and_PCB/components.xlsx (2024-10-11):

Name | Link | Amount | Price | total
PIR sensor | https://dk.rs-online.com/web/p/sensor-udvikling/8430840?gb=s | 2 | 112.66 | 225.32
RGB LED | https://dk.rs-online.com/web/p/lysdioder/8614290?gb=s | 10 | 18.5 | 185
Button | https://dk.rs-online.com/web/p/folelig-respons-afbrydere-og-omskiftere/4791429?gb=s | 20 | 0.81 | 16.2
Arduino | https://dk.rs-online.com/web/p/arduino/1927586?gb=a | 1 | 110.98 | 110.98
Potentiometer | https://dk.rs-online.com/web/p/potentiometre/7377726?gb=s | 5 | 21.04 | 105.2
Battery 9V | https://dk.rs-online.com/web/p/9-v-batterier/2095317?gb=s | 1 | 107.15 | 107.15
Battery socket | https://dk.rs-online.com/web/p/batterikontakter/1854790?gb=s | 2 | 6.64 | 13.28
 |  |  |  | 763.13

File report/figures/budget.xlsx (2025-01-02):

Component | Quantity | Price/piece [dk]* | Price of components [dk]* | Datasheet | Component | Datasheet
PIR sensor | 2 | 112.66 | 225.32 | https://docs.rs-online.com/eb35/0900766b81644fd0.pdf | PIR sensor | https://docs.rs-online.com/eb35/0900766b81644fd0.pdf
LED RGB | 10 | 18.522 | 185.22 | https://docs.rs-online.com/ad97/0900766b8139d70b.pdf | LED RGB | https://docs.rs-online.com/ad97/0900766b8139d70b.pdf
Buttons | 20 | 0.814 | 16.28 | https://docs.rs-online.com/e4fd/A700000009237051.pdf | Buttons | https://docs.rs-online.com/e4fd/A700000009237051.pdf
Arduino Nano every | 1 | 111.44 | 111.44 | https://docs.rs-online.com/1d66/A700000006519064.pdf | Arduino Nano every | https://docs.rs-online.com/1d66/A700000006519064.pdf
Potentiometer | 5 | 21.04 | 105.2 | https://docs.rs-online.com/ce7e/0900766b80fa5779.pdf | Potentiometer | https://docs.rs-online.com/ce7e/0900766b80fa5779.pdf
9V Battery | 1 | 107.15 | 107.15 | https://docs.rs-online.com/c3bb/A700000007739750.pdf | 9V Battery | https://docs.rs-online.com/c3bb/A700000007739750.pdf
Battery connector | 2 | 6.64 | 13.28 | https://docs.rs-online.com/3822/A700000006711332.pdf | Battery connector | https://docs.rs-online.com/3822/A700000006711332.pdf
Total sum |  |  | 763.89
*including VAT

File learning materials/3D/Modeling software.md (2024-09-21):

# Modeling software

From school we have [Autodesk Fusion 360](https://www.autodesk.com/education/edu-software/overview) for free. So it makes sense to use, additionaly we can combine it with [Eagle](https://www.autodesk.com/products/eagle/overview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), which should be also for free, to create 3D models of PCBs.

I didn't work with Fusion 360 so I can't help with that.

Other options for 3D modeling are:
- [TinkerCad](https://www.tinkercad.com/) - From Autodesk (web based and very easy)
- [OnShape](https://www.onshape.com/en/) - Web based free software

If you know other options you can share it here.

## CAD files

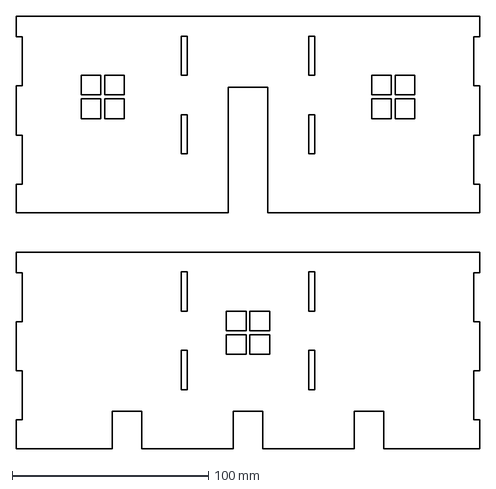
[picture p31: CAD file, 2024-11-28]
Hardware/3D_model/Walls_model/front-and-back-walls.dxf
236.0 x 220.0 mm

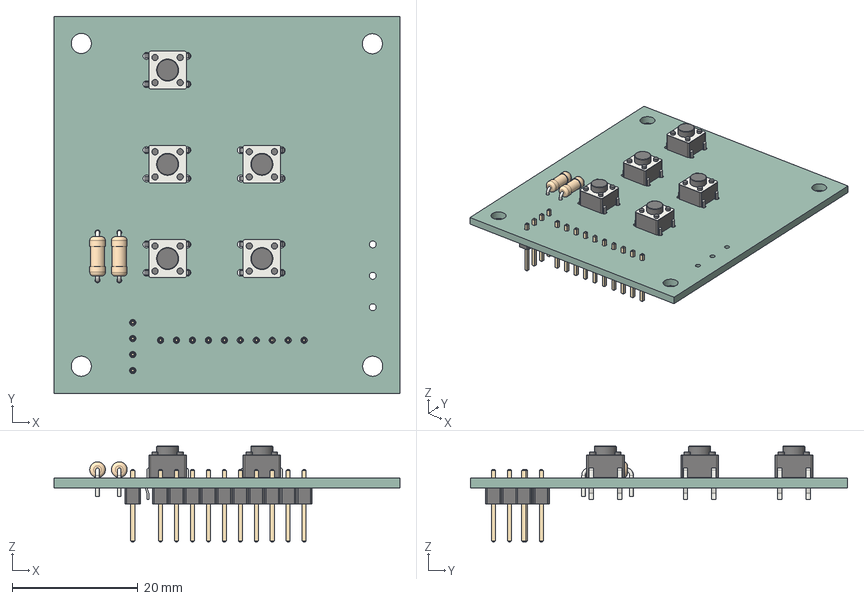
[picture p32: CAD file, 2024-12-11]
Hardware/Schematic_and_PCB/LCD_PCB/LCD_PCB.step
55.0 x 60.0 x 15.2 mm
SW_PUSH_6mm_h5mm x 5
R_Axial_DIN0207_L63mm_D25mm_P762mm_Horizontal x 2
PinHeader_1x04_P254mm_Vertical
PinHeader_1x10_P254mm_Vertical
LCD_PCB_PCB

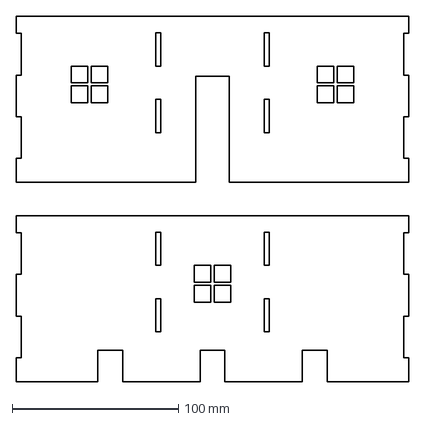
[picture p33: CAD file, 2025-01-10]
Product/Models/front-back-walls.dxf
236.0 x 220.0 mm

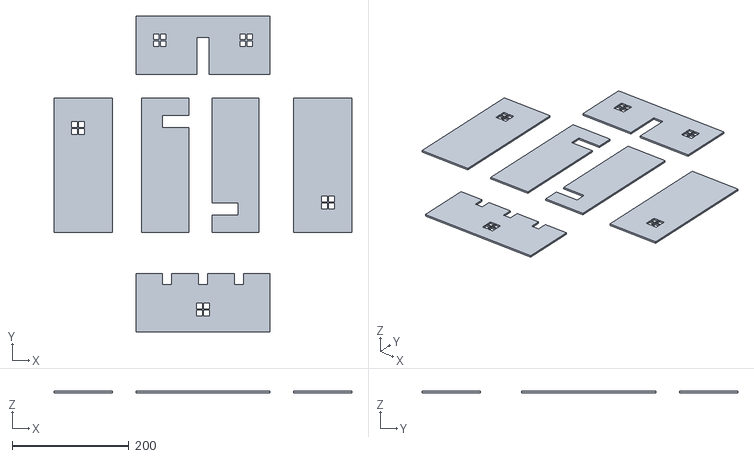
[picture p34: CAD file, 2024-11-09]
Hardware/3D_model/Walls_model/Walls v3.stl
510.0 x 540.0 x 3.00

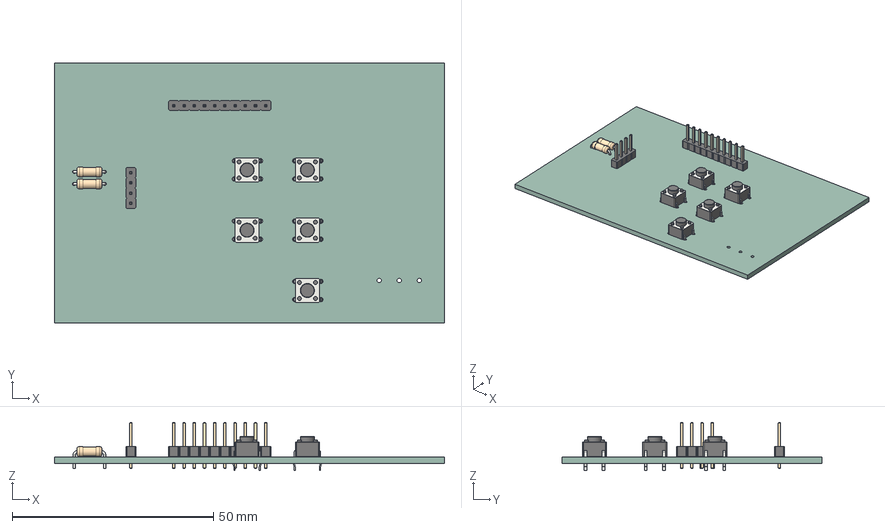
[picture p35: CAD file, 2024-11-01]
Hardware/Schematic_and_PCB/LCD_PCB/LCD_PCB._model.step
97.0 x 64.8 x 12.0 mm
SW_PUSH_6mm_h5mm x 5
R_Axial_DIN0207_L63mm_D25mm_P762mm_Horizontal x 2
PinHeader_1x04_P254mm_Vertical
PinHeader_1x10_P254mm_Vertical
LCD_PCB_PCB

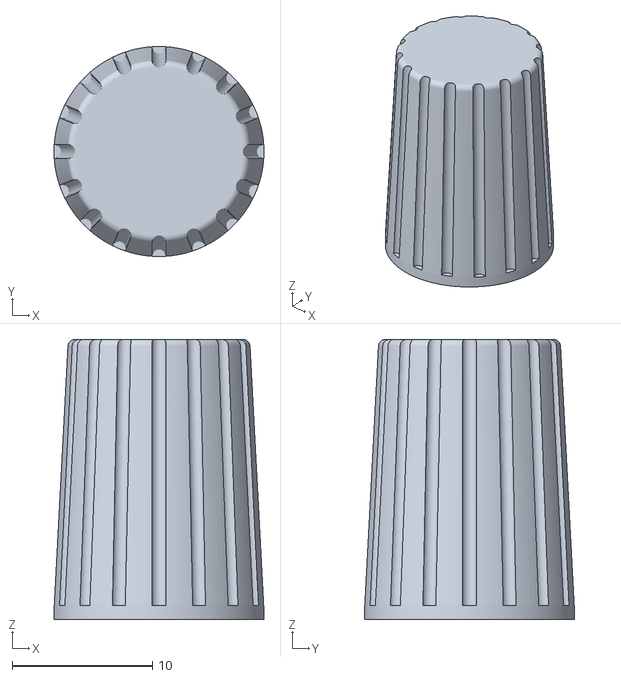
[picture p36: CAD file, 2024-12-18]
Product/Models/potentiometer cap v3.stl
15.0 x 15.0 x 20.0

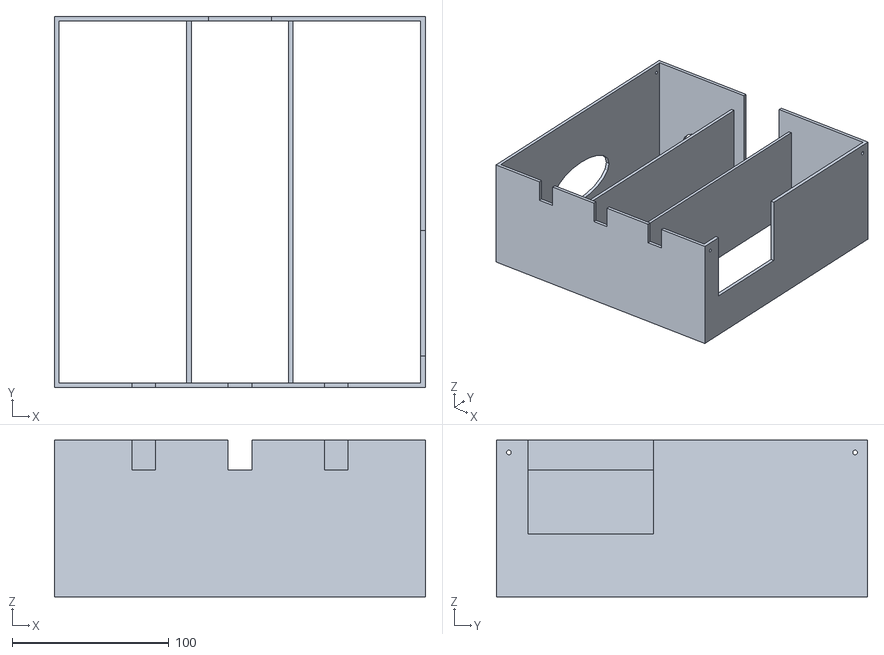
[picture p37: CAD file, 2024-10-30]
Hardware/3D_model/Walls_model/walls_with_windows.stl
236.5 x 236.5 x 100.0

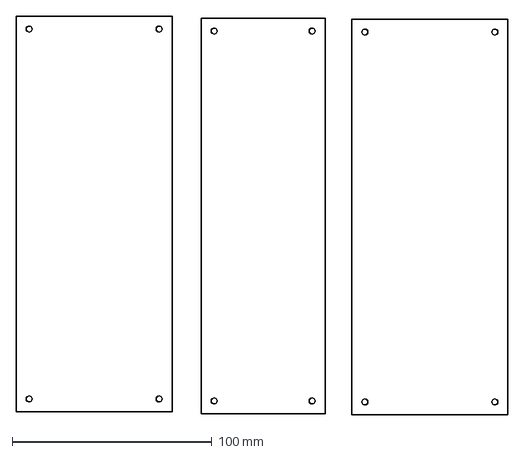
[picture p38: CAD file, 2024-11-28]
Product/Models/FloorPlates.dxf
245.9 x 199.5 mm

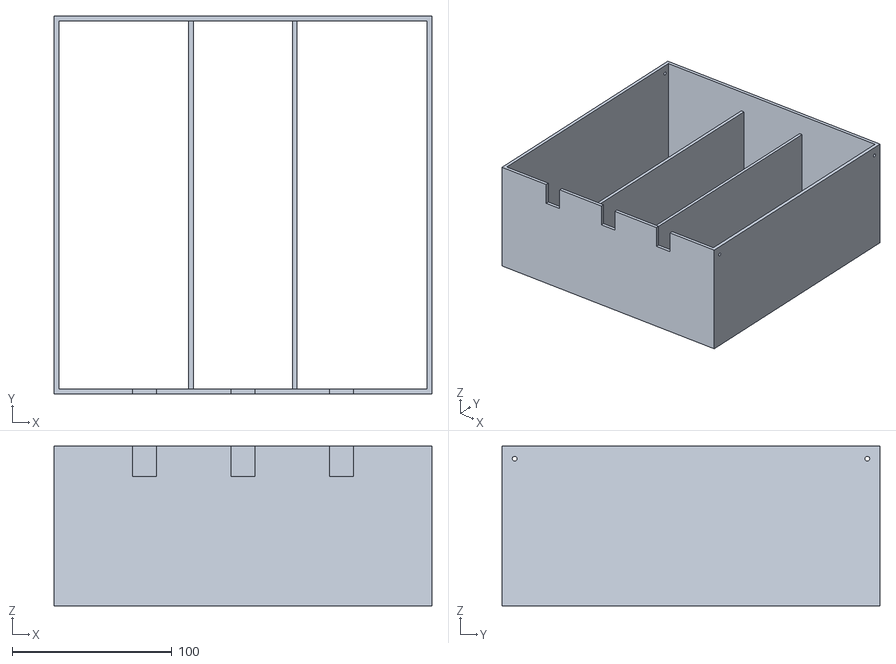
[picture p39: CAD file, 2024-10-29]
Hardware/3D_model/Walls_model/walls2.stl
236.5 x 236.5 x 100.0

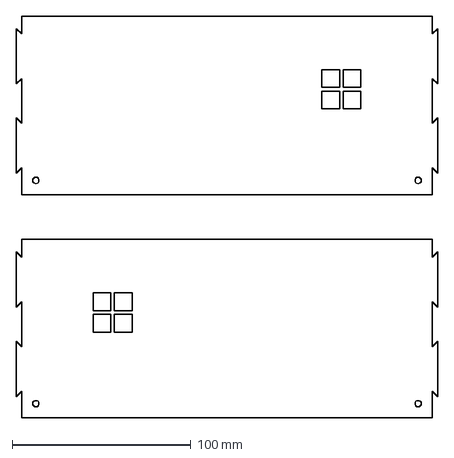
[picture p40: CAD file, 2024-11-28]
Product/Models/side-walls.dxf
236.0 x 225.0 mm

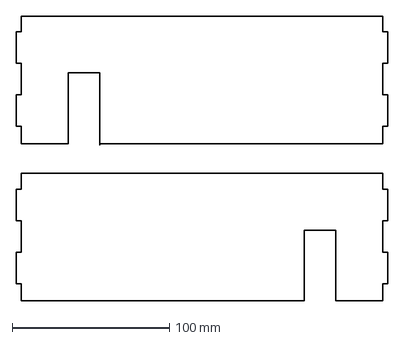
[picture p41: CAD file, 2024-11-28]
Product/Models/mid-walls.dxf
236.0 x 181.0 mm

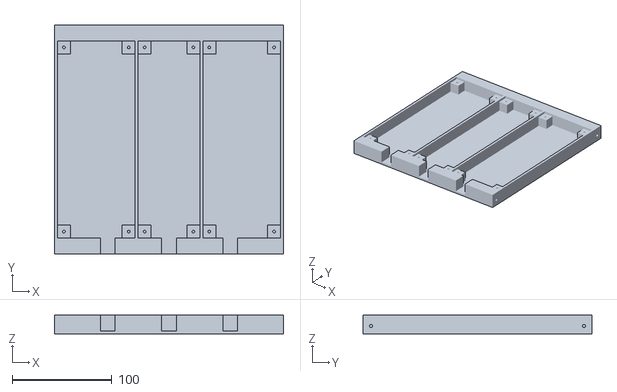
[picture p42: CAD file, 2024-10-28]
Product/Models/Base.stl
230.0 x 230.0 x 19.0

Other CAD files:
Hardware/3D_model/Floor_model/floor.gcode.3mf
Hardware/3D_model/PCB cover/PCBcoverVersion2v2NEWFORPRINT.gcode.3mf
Hardware/3D_model/PCB cover/PcbCoverAndSpacers.gcode.3mf
Hardware/3D_model/Walls_model/walls.stl
Hardware/3D_model/Potentiometers_casing/potentiometer cap v3.f3d

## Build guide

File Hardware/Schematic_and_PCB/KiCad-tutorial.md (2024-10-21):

When working with KiCad, three files are important:

- **.kicad_pro** = file with this sufix is a project file, when you open it, project view will show up with schematic and board. This file is important to connect schematic and board so baord can be updated in accordance to schematic.
- **.kicad_sch** = file with schematic.
- **.kicad_pcb** = file with board (PCB).

Usually you can use parts available in kicad but sometimes you need to import schematic symbols and footprints from other places like snapeda [here](https://youtu.be/W9cLnIjvybo) is a tutorial on how to do it.

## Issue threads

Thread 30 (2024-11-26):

Control panel logic implementation.

AiwendilsCode, 2024-11-26:
Control panel will be similar to rooms, because it will have init and update functions. Control panel will be using LCD and Menu logic, after checking buttons and pot on control panel circuit it will update menu and display accordingly.

AiwendilsCode, 2024-11-26:
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
Maybe this image will help to visualize program logic.

Closed 2025-01-09.

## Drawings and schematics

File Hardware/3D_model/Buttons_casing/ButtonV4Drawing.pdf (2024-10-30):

.2mm7.9mm ¹mm .3mm | .9mm | 3.5mm .9mm .3mm | 1mm
.2 7.9mm | 5.9mm

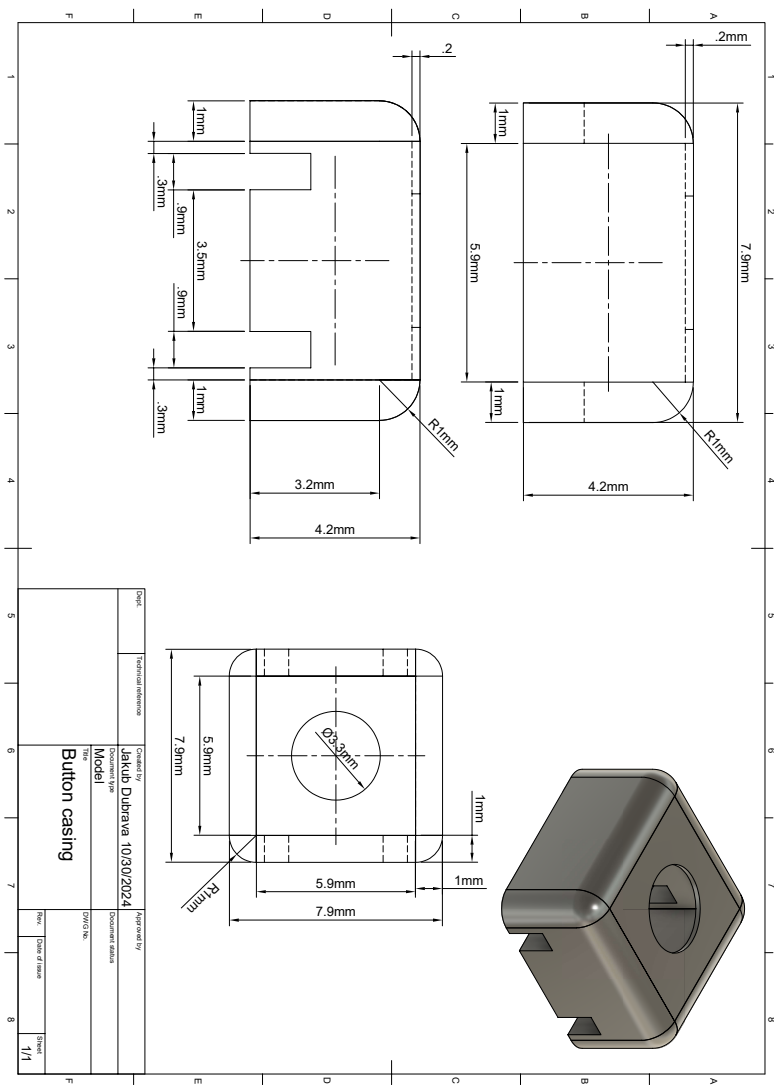
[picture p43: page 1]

1 A 2 3 4 5 6 7 8 1 2 3 4 5 6 7 8 FEDCB FEDCBA Dept. Technical reference Created by Approved by Title DWG No. Document type Document status Rev. Date of issue Sheet Model 10/30/2024 1/1 Button casing Jakub Dubrava 1mm 5.9mm 1mm

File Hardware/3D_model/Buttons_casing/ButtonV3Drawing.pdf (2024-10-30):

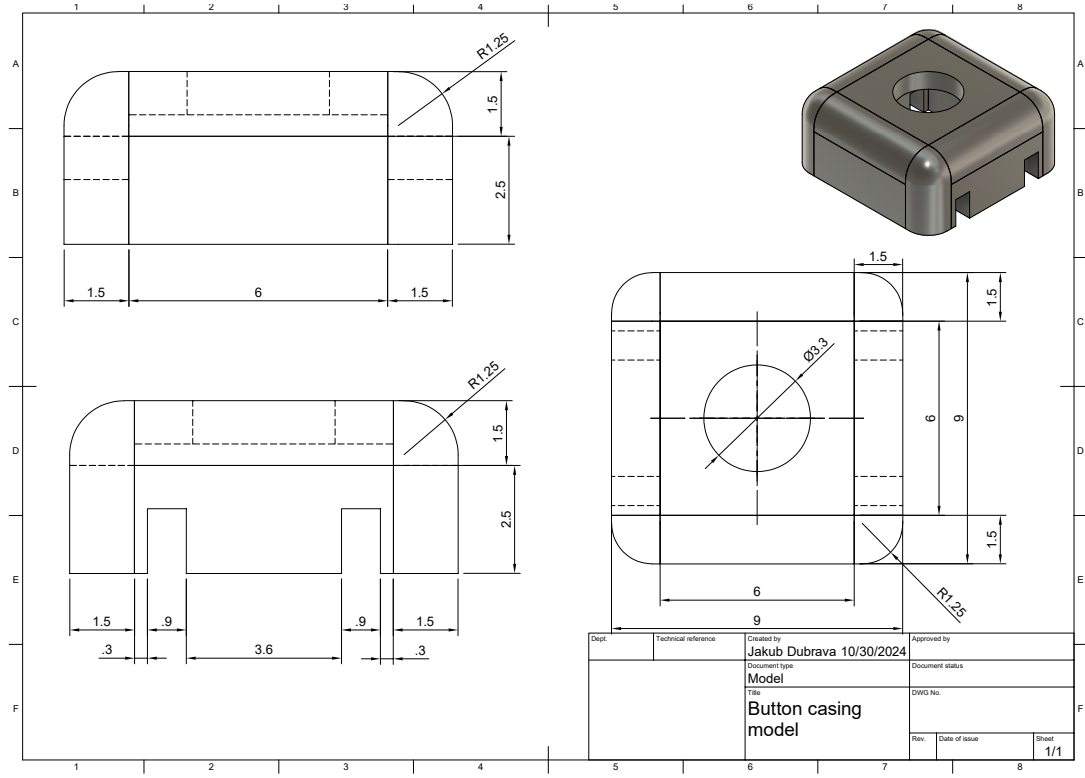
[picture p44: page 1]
8 BCDEF; ABCDEF Dept.; Technical reference; Created by; Approved by Document type; Document status Title; DWG No. Rev.; Date of issue; Sheet Model; 1/1 model Button casing Jakub Dubrava 1.5

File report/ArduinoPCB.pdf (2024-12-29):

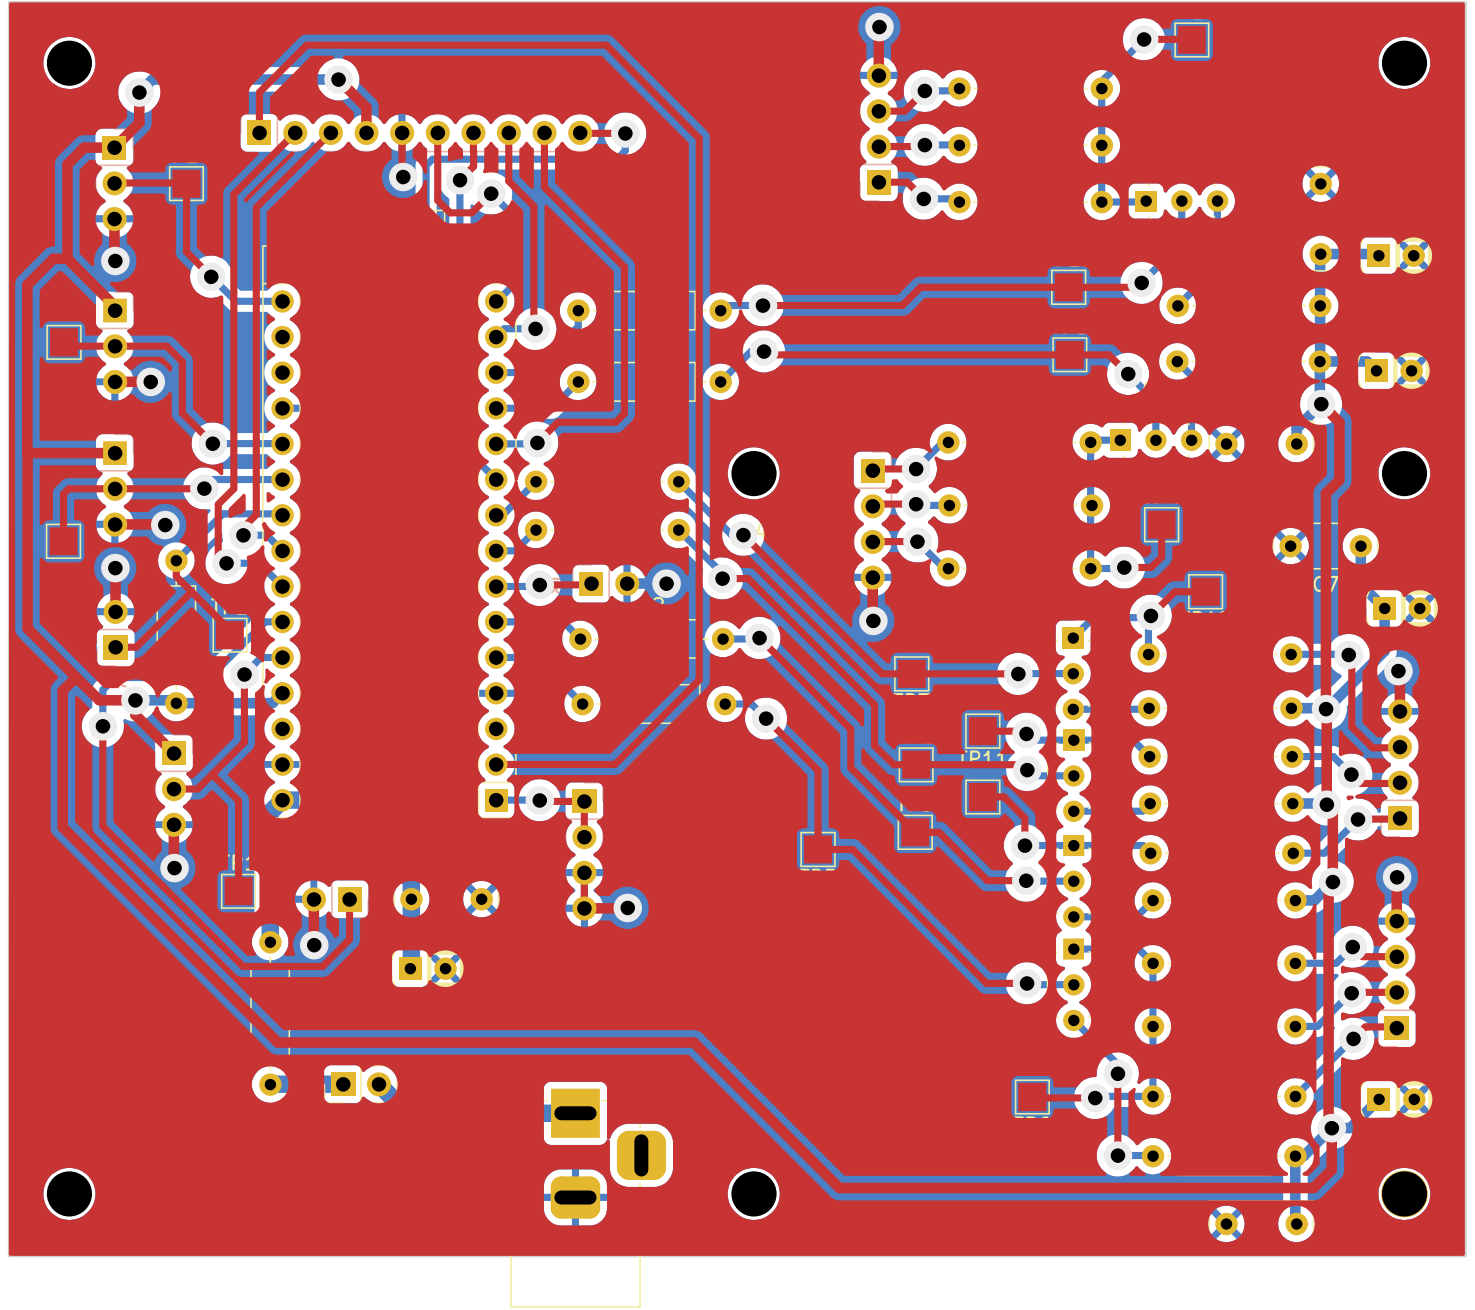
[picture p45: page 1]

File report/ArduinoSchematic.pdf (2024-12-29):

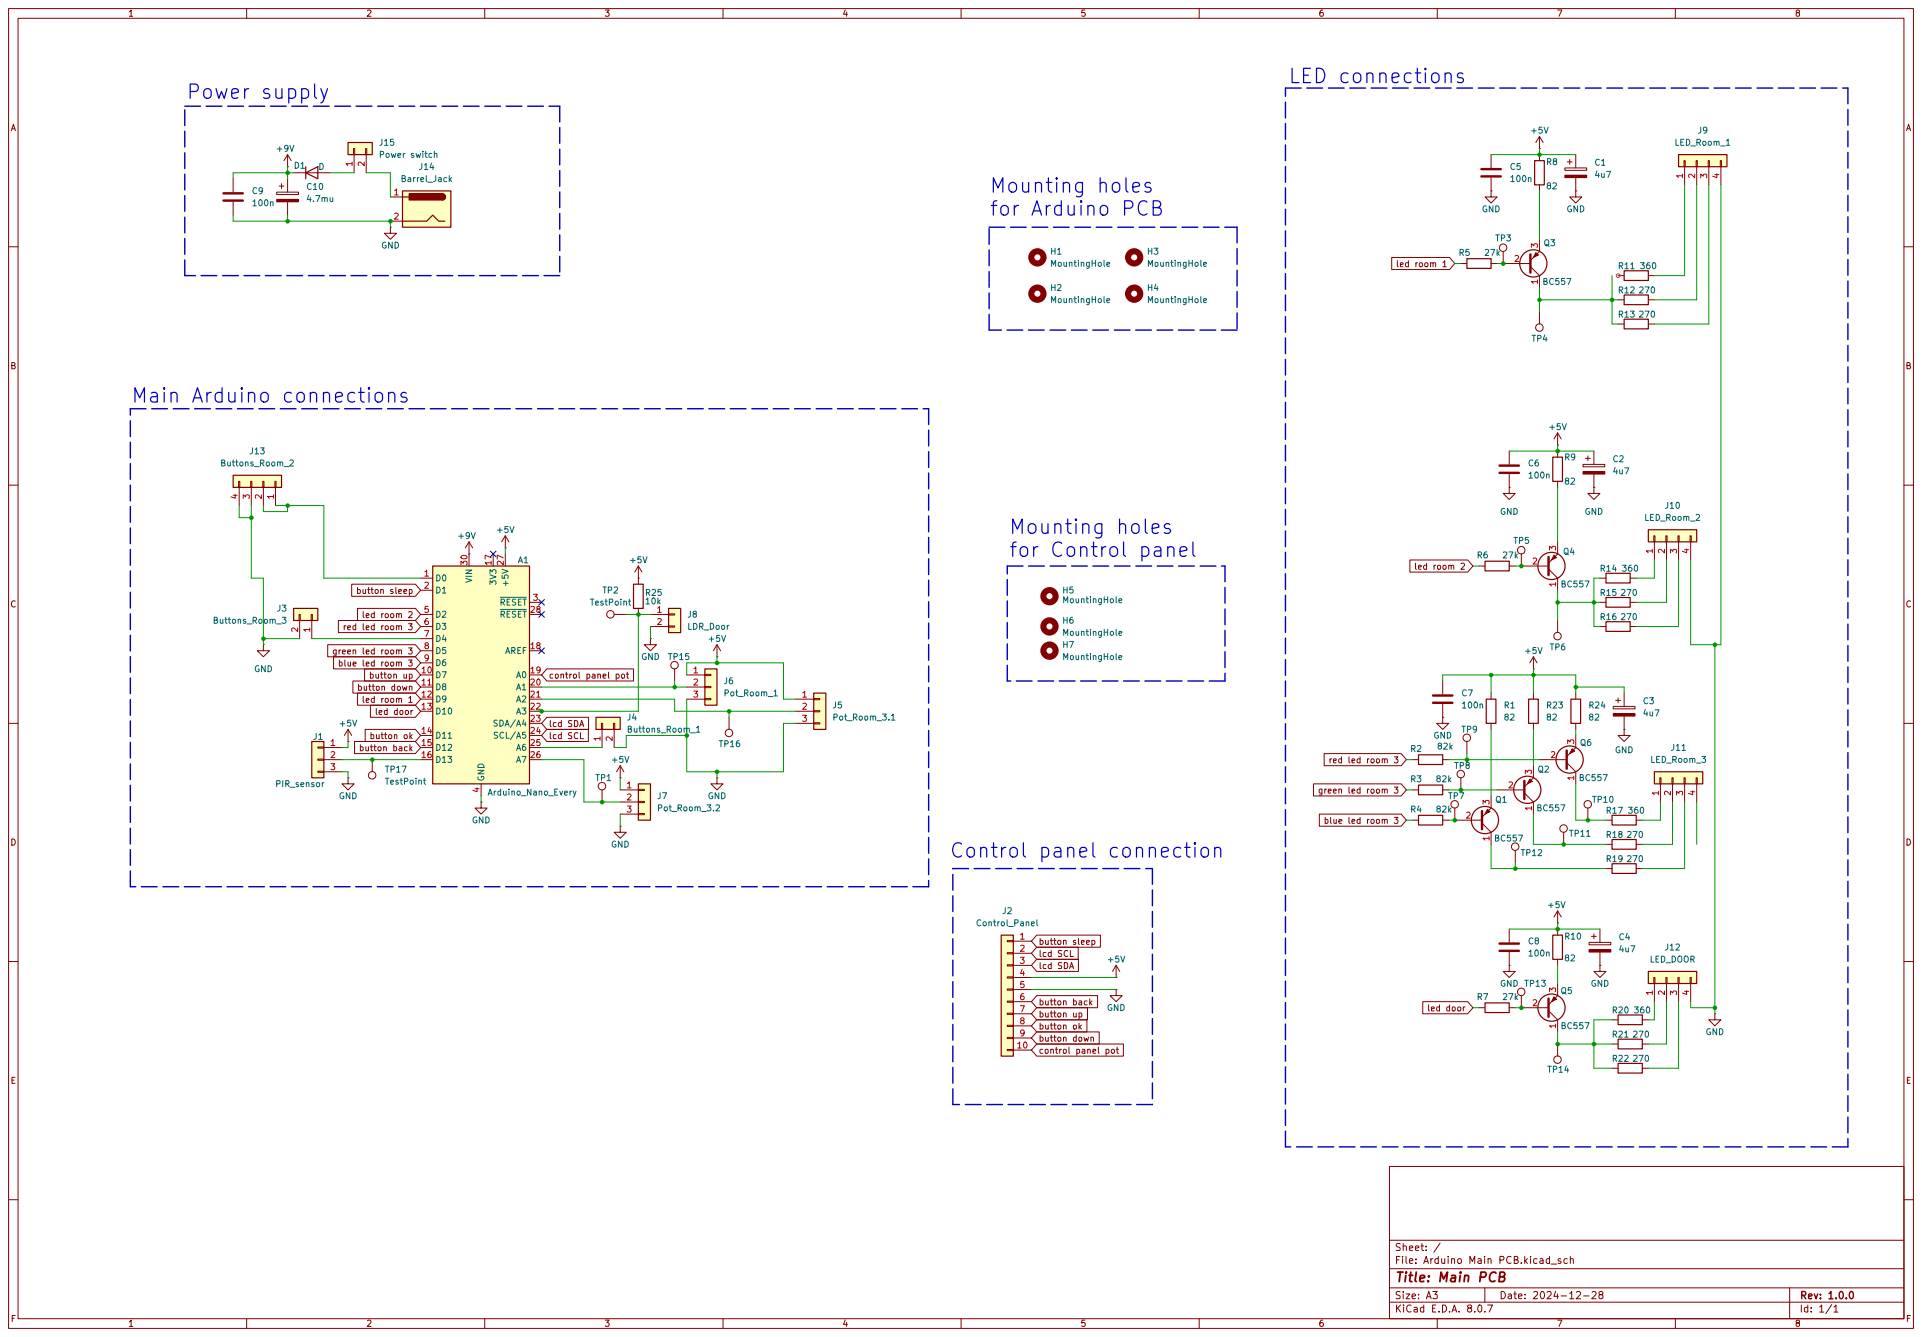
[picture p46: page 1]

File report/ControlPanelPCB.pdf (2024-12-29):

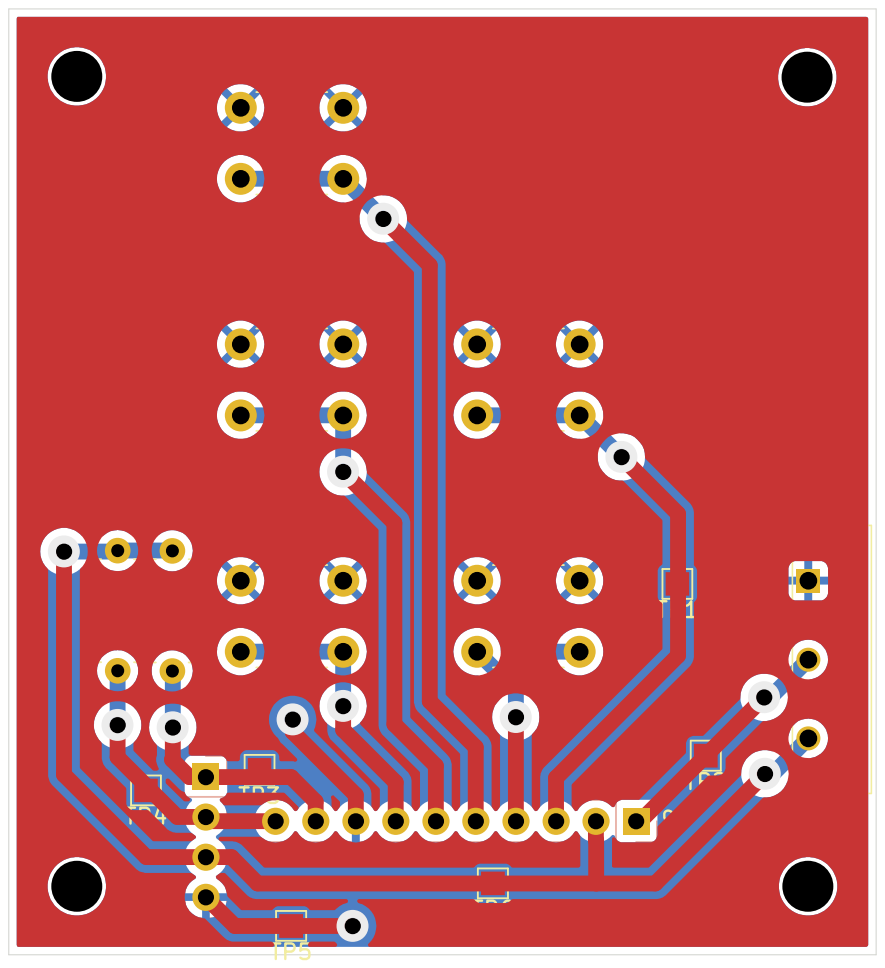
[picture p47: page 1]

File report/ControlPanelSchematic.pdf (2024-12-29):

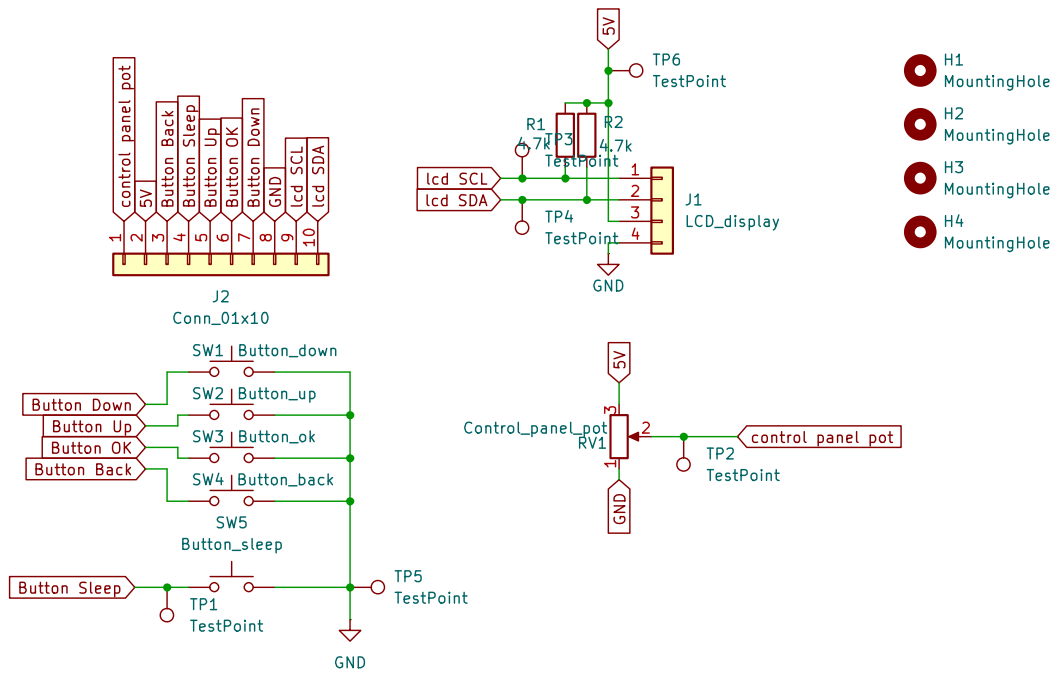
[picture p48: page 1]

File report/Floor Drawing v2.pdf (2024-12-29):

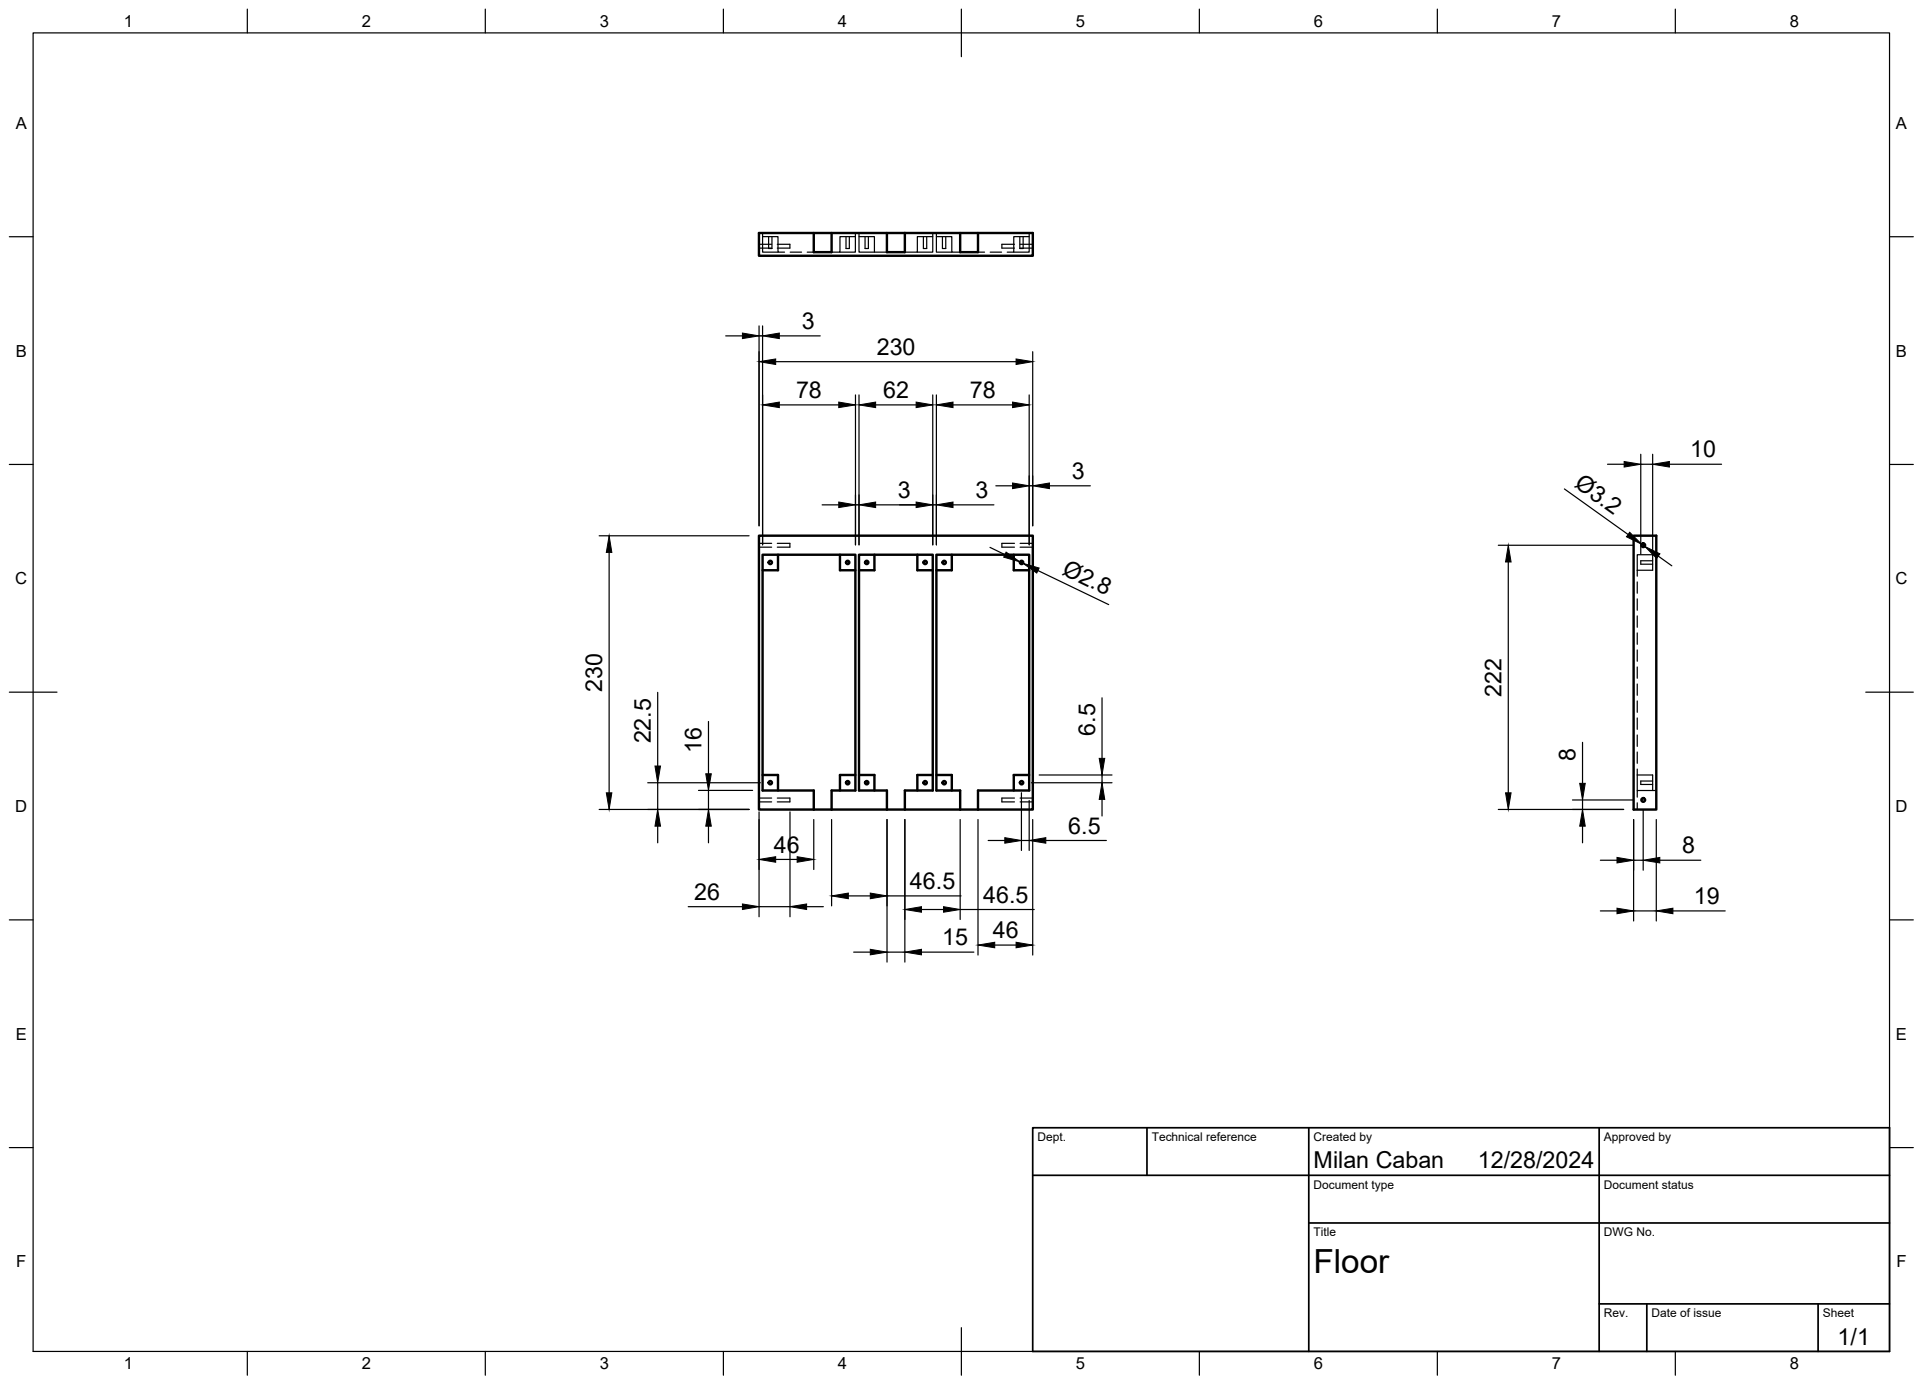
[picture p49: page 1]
Title; DWG No.; Rev.; Date of issue; Sheet

Dept. | Technical reference | Created by Milan Caban 12/28/2024 | Approved by

Document type | Document status

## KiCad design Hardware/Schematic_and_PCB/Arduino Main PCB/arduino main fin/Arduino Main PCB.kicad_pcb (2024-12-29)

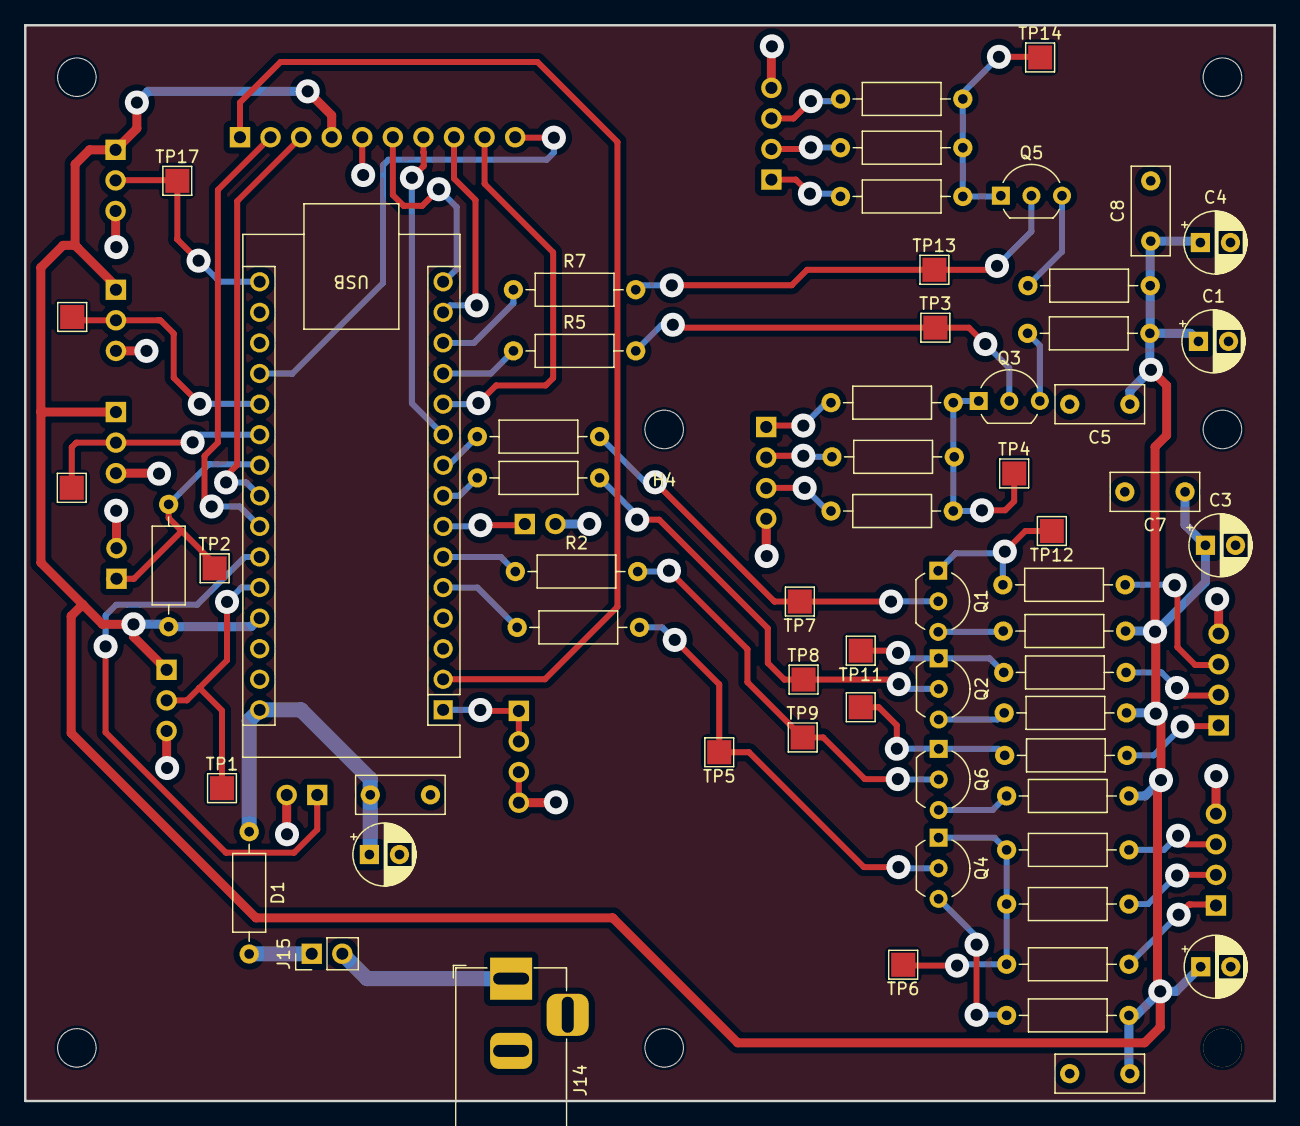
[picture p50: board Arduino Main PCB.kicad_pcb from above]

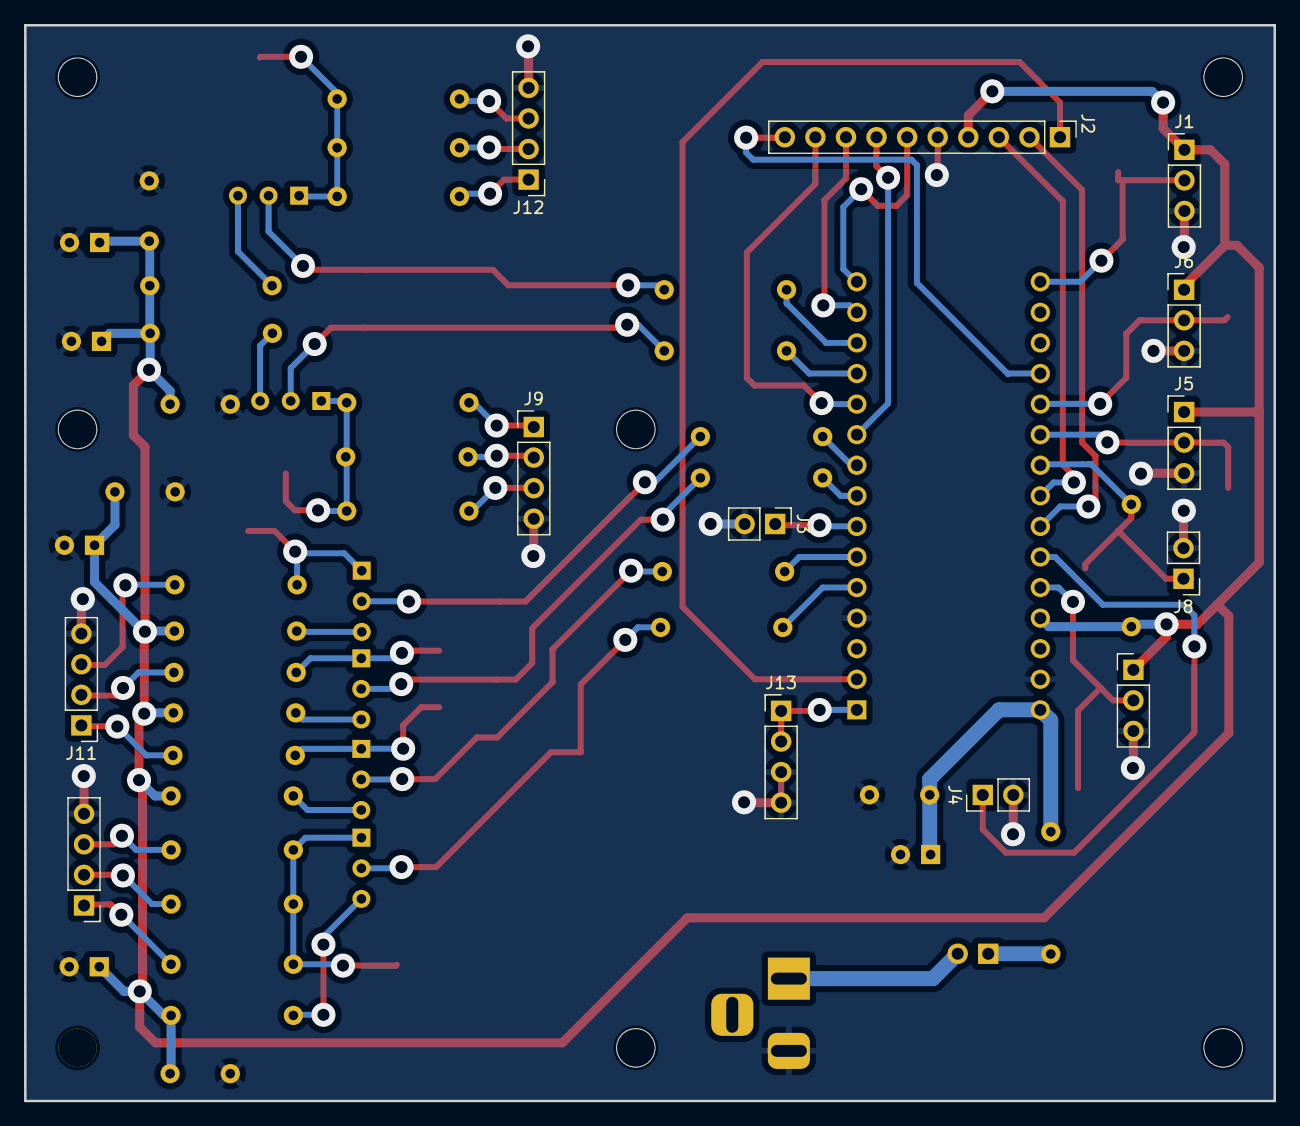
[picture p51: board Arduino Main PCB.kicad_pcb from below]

Board: 2 copper layers, 103.8 x 89.4 mm, 82 parts (13 on the bottom side), 57 nets.

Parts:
A1: Arduino_Nano_Every; Arduino_Nano
C1, C2, C3, C4, C10: 4.7mu; CP_Radial_D5.0mm_P2.50mm
C5, C6, C7, C8, C9: 100n; C_Rect_L7.2mm_W3.0mm_P5.00mm_FKS2_FKP2_MKS2_MKP2
D1: D; R_Axial_DIN0207_L6.3mm_D2.5mm_P10.16mm_Horizontal
H1, H2, H3, H4, H5, H6, H7: MountingHole; MountingHole_3.2mm_M3
J1: PIR_sensor; PinHeader_1x03_P2.54mm_Vertical
J2: Control_Panel; PinHeader_1x10_P2.54mm_Vertical
J3: Buttons_Room_3; PinHeader_1x02_P2.54mm_Vertical
J4: Buttons_Room_1; PinHeader_1x02_P2.54mm_Vertical
J5: Pot_Room_3.1; PinHeader_1x03_P2.54mm_Vertical
J6: Pot_Room_1; PinHeader_1x03_P2.54mm_Vertical
J7: Pot_Room_3.2; PinHeader_1x03_P2.54mm_Vertical
J8: LDR_Door; PinHeader_1x02_P2.54mm_Vertical
J9: LED_Room_1; PinHeader_1x04_P2.54mm_Vertical
J10: LED_Room_2; PinHeader_1x04_P2.54mm_Vertical
J11: LED_Room_3; PinHeader_1x04_P2.54mm_Vertical
J12: LED_DOOR; PinHeader_1x04_P2.54mm_Vertical
J13: Buttons_Room_2; PinHeader_1x04_P2.54mm_Vertical
J14: Barrel_Jack; BarrelJack_Horizontal
J15: Power switch; PinHeader_1x02_P2.54mm_Vertical
Q1, Q2, Q3, Q4, Q5, Q6: BC557; TO-92_Inline_Wide
R1, R8, R9, R10, R23, R24, R25: 80; R_Axial_DIN0207_L6.3mm_D2.5mm_P10.16mm_Horizontal
R2, R3, R4: 82k; R_Axial_DIN0207_L6.3mm_D2.5mm_P10.16mm_Horizontal
R5, R6, R7: 1k; R_Axial_DIN0207_L6.3mm_D2.5mm_P10.16mm_Horizontal
R11, R14, R20: 650; R_Axial_DIN0207_L6.3mm_D2.5mm_P10.16mm_Horizontal
R12, R13, R15, R16, R21, R22: 450; R_Axial_DIN0207_L6.3mm_D2.5mm_P10.16mm_Horizontal
R17: 330; R_Axial_DIN0207_L6.3mm_D2.5mm_P10.16mm_Horizontal
R18, R19: 220; R_Axial_DIN0207_L6.3mm_D2.5mm_P10.16mm_Horizontal
TP1, TP2, TP3, TP4, TP5, TP6, TP7, TP8, TP9, TP10, TP11, TP12, TP13, TP14, TP15, TP16, TP17: TestPoint; TestPoint_Pad_2.0x2.0mm

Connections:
+5V: A1.27 (+5V), C1.1, C2.1, C3.1, C4.1, C5.1, C6.1, C7.1, C8.1, J1.1, J2.4, J5.1, J6.1, J7.1, R1.1, R8.1, R9.1, R10.1, R23.1, R24.1, R25.1
+9V: A1.30 (VIN), C9.1, C10.1, D1.1 (K)
GND: A1.4 (GND), A1.29 (GND), C1.2, C2.2, C3.2, C4.2, C5.2, C6.2, C7.2, C8.2, C9.2, C10.2, J1.3, J2.5, J3.2, J4.2, J5.3, J6.3, J7.3, J8.2, J9.4, J10.4, J11.4, J12.4, J13.3, J13.4, J14.2
unnamed: A1.20 (A1), J6.2, TP15.1
unnamed: A1.21 (A2), J5.2, TP16.1
unnamed: A1.22 (A3), J8.1, R25.2, TP2.1
unnamed: A1.25 (A6), J4.1
unnamed: A1.26 (A7), J7.2, TP1.1
unnamed: A1.1 (D0), J13.1, J13.2
unnamed: A1.7 (D4), J3.1
unnamed: A1.16 (D13), J1.2, TP17.1
unnamed: D1.2 (A), J15.1
unnamed: J9.1, R11.2
unnamed: J9.2, R12.2
unnamed: J9.3, R13.2
unnamed: J10.1, R14.2
unnamed: J10.2, R15.2
unnamed: J10.3, R16.2
unnamed: J11.1, R17.2
unnamed: J11.2, R18.2
unnamed: J11.3, R19.2
unnamed: J12.1, R20.2
unnamed: J12.2, R21.2
unnamed: J12.3, R22.2
unnamed: J14.1, J15.2
unnamed: Q1.2 (B), R4.2, TP7.1
unnamed: Q1.1 (C), R19.1, TP12.1
unnamed: Q1.3 (E), R1.2
unnamed: Q2.2 (B), R3.2, TP8.1
unnamed: Q2.1 (C), R18.1, TP11.1
unnamed: Q2.3 (E), R23.2
unnamed: Q3.2 (B), R5.2, TP3.1
unnamed: Q3.1 (C), R11.1, R12.1, R13.1, TP4.1
unnamed: Q3.3 (E), R8.2
unnamed: Q4.2 (B), R6.2, TP5.1
unnamed: Q4.1 (C), R14.1, R15.1, R16.1, TP6.1
unnamed: Q4.3 (E), R9.2
unnamed: Q5.2 (B), R7.2, TP13.1
unnamed: Q5.1 (C), R20.1, R21.1, R22.1, TP14.1
unnamed: Q5.3 (E), R10.2
unnamed: Q6.2 (B), R2.2, TP9.1
unnamed: Q6.1 (C), R17.1, TP10.1
unnamed: Q6.3 (E), R24.2
blue led room 3: A1.9 (D6), R4.1
button back: A1.15 (D12), J2.6
button down: A1.11 (D8), J2.9
button ok: A1.14 (D11), J2.8
button sleep: A1.2 (D1), J2.1
button up: A1.10 (D7), J2.7
control panel pot: A1.19 (A0), J2.10
green led room 3: A1.8 (D5), R3.1
lcd SCL: A1.24 (SCL/A5), J2.2
lcd SDA: A1.23 (SDA/A4), J2.3
led door: A1.13 (D10), R7.1
led room 1: A1.12 (D9), R5.1
led room 2: A1.5 (D2), R6.1
red led room 3: A1.6 (D3), R2.1

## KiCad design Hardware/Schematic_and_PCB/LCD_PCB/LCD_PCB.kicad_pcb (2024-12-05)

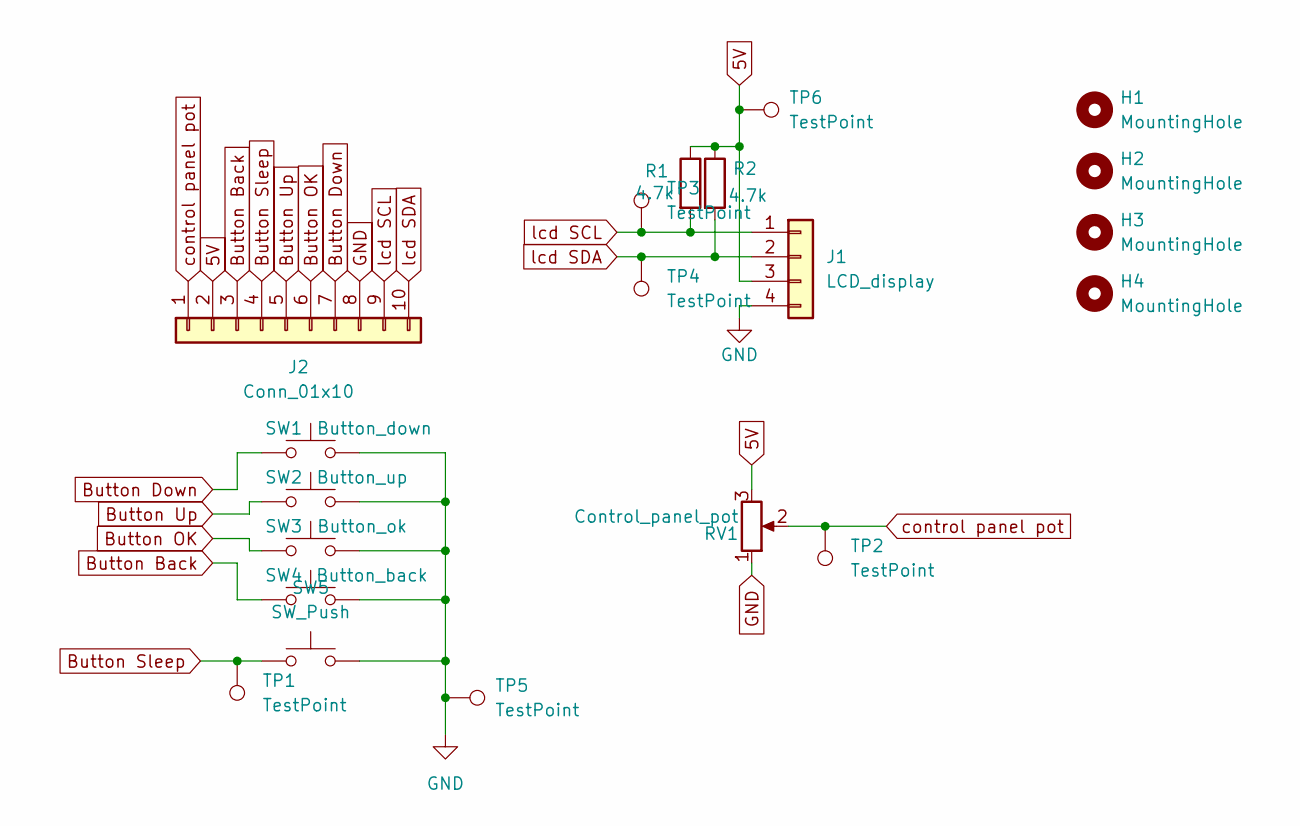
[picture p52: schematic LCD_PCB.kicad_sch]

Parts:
H1, H2, H3, H4: MountingHole; MountingHole_3.2mm_M3
J1: LCD_display; PinHeader_1x04_P2.54mm_Vertical
J2: Conn_01x10; PinHeader_1x10_P2.54mm_Vertical
R1, R2: 4.7k; R_Axial_DIN0207_L6.3mm_D2.5mm_P7.62mm_Horizontal
RV1: Control_panel_pot; PDB182-K-Potentiometer-Horizontal
SW1: Button_down; SW_PUSH_6mm_H5mm
SW2: Button_up; SW_PUSH_6mm_H5mm
SW3: Button_ok; SW_PUSH_6mm_H5mm
SW4: Button_back; SW_PUSH_6mm_H5mm
SW5: SW_Push; SW_PUSH_6mm_H5mm
TP1, TP2, TP3, TP4, TP5, TP6: TestPoint; TestPoint_Pad_1.5x1.5mm

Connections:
5V: J1.3, J2.2, R1.1, R2.1, RV1.3, TP6.1
Button Back: J2.3, SW4.1
Button Down: J2.7, SW1.1
Button OK: J2.6, SW3.1
Button Sleep: J2.4, SW5.1, TP1.1
Button Up: J2.5, SW2.1
GND: J1.4, J2.8, RV1.1, SW1.2, SW2.2, SW3.2, SW4.2, SW5.2, TP5.1
control panel pot: J2.1, RV1.2, TP2.1
lcd SCL: J1.1, J2.9, R1.2, TP3.1
lcd SDA: J1.2, J2.10, R2.2, TP4.1

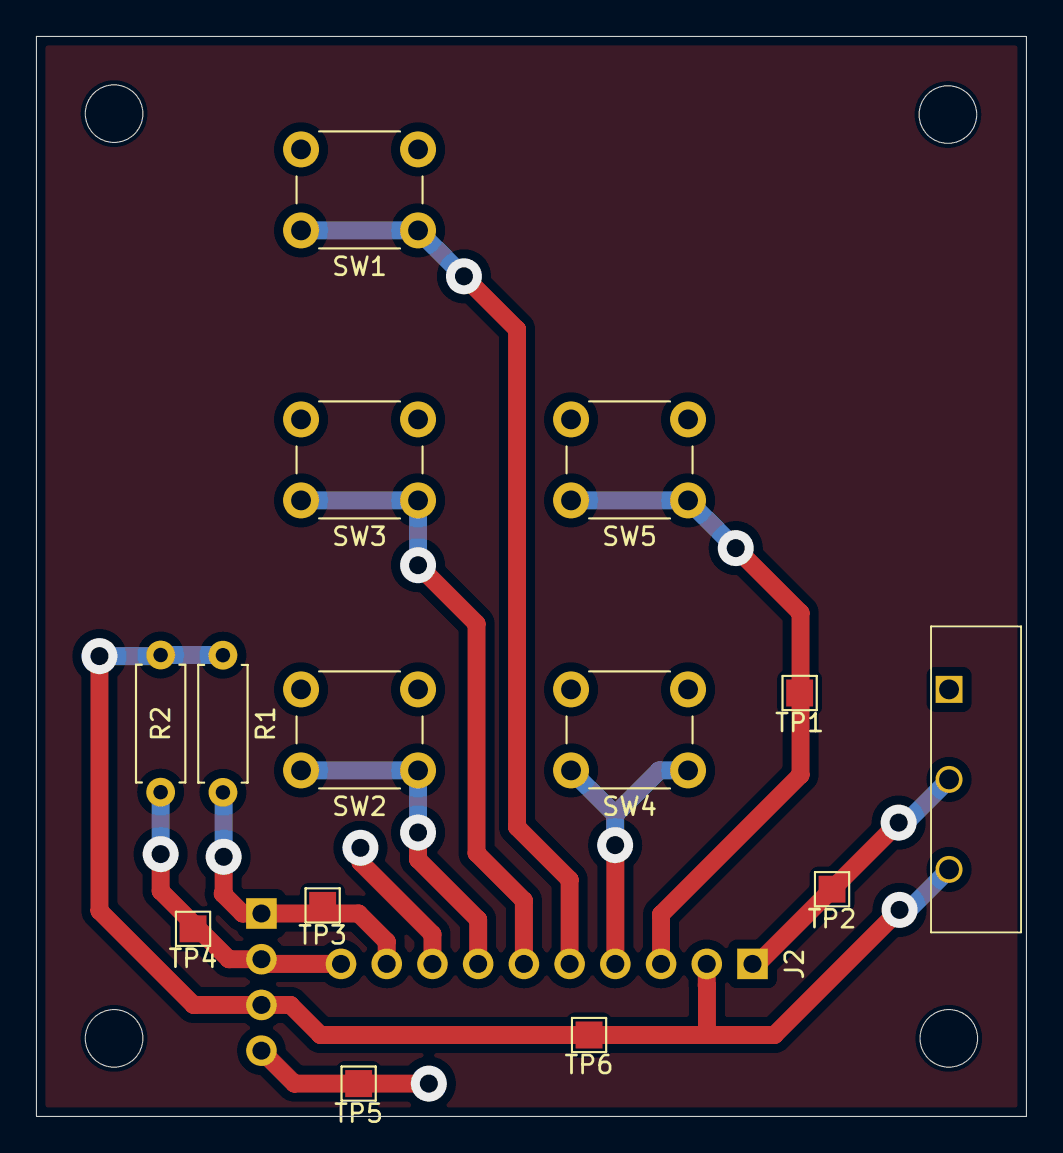
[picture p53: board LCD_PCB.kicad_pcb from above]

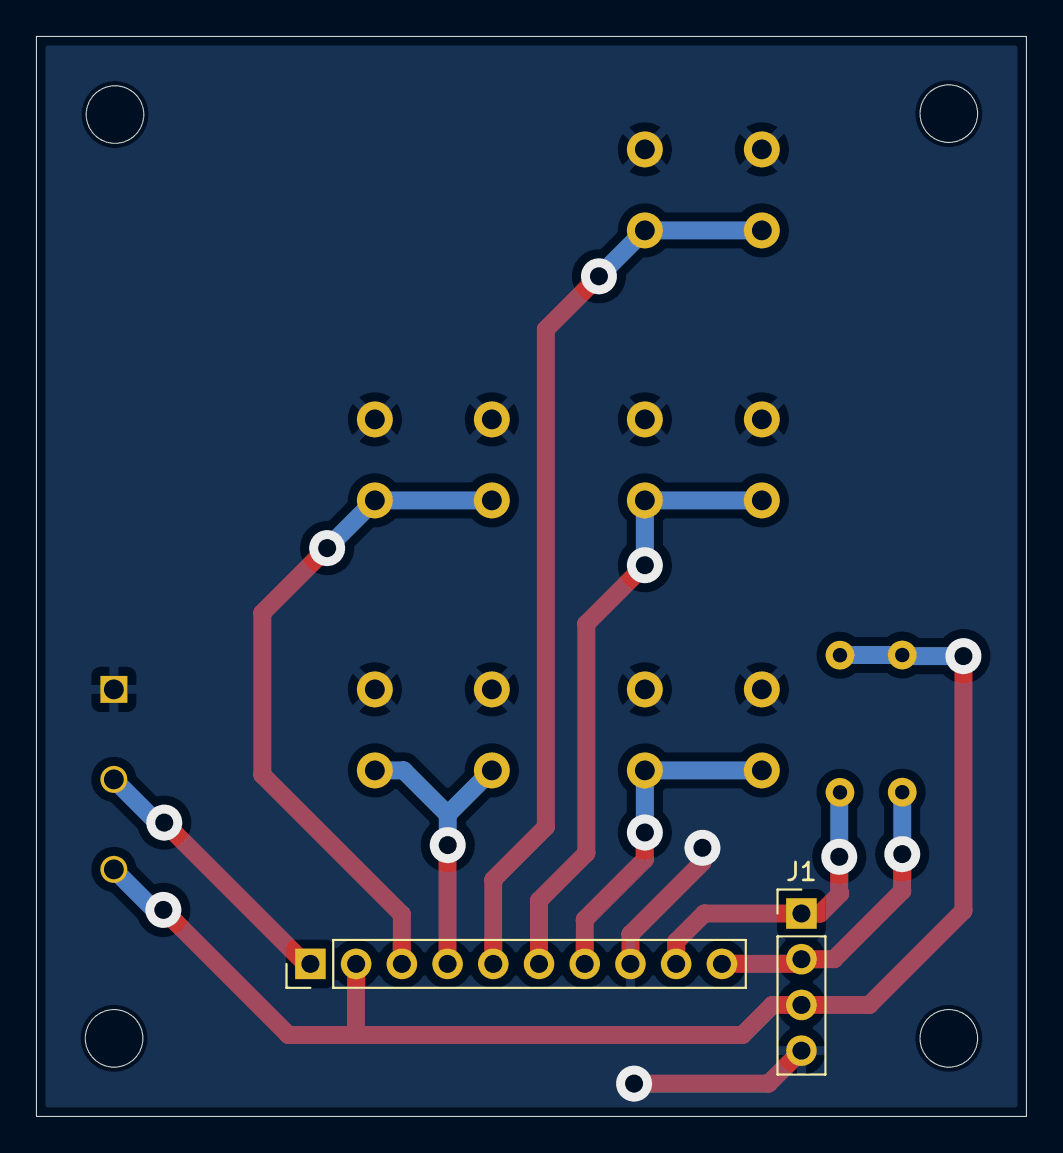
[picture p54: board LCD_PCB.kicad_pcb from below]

Board: 2 copper layers, 55.0 x 60.0 mm, 20 parts (2 on the bottom side), 10 nets.

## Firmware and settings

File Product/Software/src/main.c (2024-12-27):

// standard libraries
#include <stdio.h>
#include <avr/io.h>
#include <util/delay.h>

// Alin's libraries
#include "usart.h"
#include "lcd.h"
#include "adcpwm.h"

// Our libraries ☭
#include "room_1.h"
#include "room_2.h"
#include "room_3.h"
#include "door.h"
#include "control_panel.h"

int main(void)
{
  init_room_1();
  init_room_2();
  init_room_3();
  init_door();

  init_control_panel();
  
  while(1)
  {
    update_room_1();
    update_room_2();
    update_room_3();
    update_door();

    update_control_panel();
  }
}

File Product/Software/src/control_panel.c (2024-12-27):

#include <control_panel.h>
#include <menu.h>
#include <display.h>
#include <avr/io.h>
#include <adcpwm.h>
#include <stdio.h>
#include <util/delay.h>

#include <mediator.h>

#define SDU_BOARD_TESTING 0

#if !SDU_BOARD_TESTING
#define BTN_UP      7 // port D
#define BTN_DOWN    0 // port B
#define BTN_SELECT  3 // port B
#define BTN_BACK    4 // port B
#else
#define BTN_UP      0 // port C
#define BTN_DOWN    1 // port C
#define BTN_SELECT  2 // port C
#define BTN_BACK    3 // port C
#endif

enum
{
    IN_MENU,
    IN_FLOAT_ELM,
    IN_BOOL_ELM,
    IN_ENUM_ELM,
} current_position;

typedef enum
{
    PRESS_BTN_UP,
    PRESS_BTN_DOWN,
    PRESS_BTN_SELECT,
    PRESS_BTN_BACK,
    CHANGE_POT,
    NOTHING
} What_happened;

void show_curr_elems_on_display();

int check_btn_up()
{
    if ((PIND & (1 << BTN_UP)) == 0)
    {
        _delay_ms(100);
        return 1;
    }

    return 0;
}

int check_btn_down()
{
    if ((PINB & (1 << BTN_DOWN)) == 0)
    {
        _delay_ms(100);
        return 1;
    }

    return 0;
}

int check_btn_select()
{
    if ((PINB & (1 << BTN_SELECT)) == 0)
    {
        _delay_ms(100);
        return 1;
    }

    return 0;
}

int check_btn_back()
{
    if ((PINB & (1 << BTN_BACK)) == 0)
    {
        _delay_ms(100);
        return 1;
    }

    return 0;
}

void init_control_panel()
{
    init_display();
    init_menu();
    //adc_init();

    // set input and pull up for button up
    DDRD &= ~(1 << BTN_UP);
    PORTD |= (1 << BTN_UP);

    // set input and pull up for button down
    DDRB &= ~(1 << BTN_DOWN);
    PORTB |= (1 << BTN_DOWN);

    // set input and pull up for button select
    DDRB &= ~(1 << BTN_SELECT);
    PORTB |= (1 << BTN_SELECT);

    // set input and pull up for button back
    DDRB &= ~(1 << BTN_BACK);
    PORTB |= (1 << BTN_BACK);

    show_curr_elems_on_display();
}

void show_curr_elems_on_display()
{
    int elms_count;
    Menu_element* elms[4];
    get_current_elms(elms, &elms_count);

    int hovered_elm = get_hovered_elm_idx();
    int selected_elm = get_selected_elm_idx();
/*
    for (int i = 0; i < elms_count; i++)
    {
        if (i == hovered_elm - 1)
        {
            printf("* ");
        }
        else if (i == selected_elm - 1)
        {
            printf("> ");
        }
        else
        {
            printf("  ");
        }

        if (elms[i]->type == MENU_FILE)
        {
            printf("%s ", elms[i]->element.file.Name);
            printf("%3.2f", elms[i]->element.file.value);
        }
        else if (elms[i]->type == MENU_FOLDER)
        {
            printf("%s", elms[i]->element.folder.Name);
        }

        printf("\n");
    }*/

    update_display(elms, elms_count, hovered_elm, selected_elm);
}

void react_btn_up_pressed()
{
    Move_up();
    show_curr_elems_on_display();
}

void react_btn_down_pressed()
{
    Move_down();
    show_curr_elems_on_display();
}

void react_btn_select_pressed()
{
    Select();
    show_curr_elems_on_display();
}

void react_btn_back_pressed()
{
    Back();
    show_curr_elems_on_display();
}

void react_pot_value_changed()
{
    
}

What_happened check_controls()
{
    if (check_btn_select())
    {
        return PRESS_BTN_SELECT;
    }

    if (check_btn_up())
    {
        return PRESS_BTN_UP;
    }

    if (check_btn_down())
    {
        return PRESS_BTN_DOWN;
    }

    if (check_btn_back())
    {
        return PRESS_BTN_BACK;
    }

    return NOTHING;
}

void update_control_panel()
{/*
    char pressed_control;

    printf("Enter control: ");
    scanf("%c", &pressed_control);
    printf("\n");

    switch(pressed_control)
    {
        case 'w': // up
            react_btn_up_pressed();
            break;
        case 's': // select
            react_btn_select_pressed();
            break;
        case 'z': // down
            react_btn_down_pressed();
            break;
        case 'q': // back
            react_btn_back_pressed();
            break;
    }*/
    
    switch(check_controls())
    {
        case PRESS_BTN_UP:
            react_btn_up_pressed();
            break;
        case PRESS_BTN_DOWN:
            react_btn_down_pressed();
            break;
        case PRESS_BTN_SELECT:
            react_btn_select_pressed();
            break;
        case PRESS_BTN_BACK:
            react_btn_back_pressed();
            break;
        case CHANGE_POT:
            react_pot_value_changed();
            break;
        case NOTHING:
            break;
    }

    Menu_element* curr_elems[4];
    int element_count;

    get_current_elms(curr_elems, &element_count);

    for (int i = 0; i < element_count; i++)
    {
        if (curr_elems[i]->type == MENU_FILE)
        {
            get_value_func get_value = get_getter_func(curr_elems[i]->element.file.ID);
            if (get_value != 0) 
            {
                float new_value = get_value();

                if (new_value != curr_elems[i]->element.file.value)
                {
                    curr_elems[i]->element.file.value = new_value;
                    update_file_element(curr_elems[i]);
                }
            }
        }
    }

/*
    switch (curr_element->type)
    {
        case MENU_FOLDER:
            current_position = IN_MENU;
            break;
        case MENU_FILE:
            if (curr_element->element.file.selected)
            {
                switch (curr_element->element.file.type)
                {
                    case FLOAT:
                        current_position = IN_FLOAT_ELM;
                        break;
                    case BOOL:
                        current_position = IN_BOOL_ELM;
                        break;
                }
            }
            else
            {
                current_position = IN_MENU;
            }
    }*/
    
}

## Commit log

2024-09-20 Add some learning materials for GitHub.
2024-09-21 Finish learning materials for GitHub.
2024-09-21 Add notes for PCB design.
2024-09-21 Add notes for Arduino.
2024-09-26 Move the chart to project assignments folder for organization
    [Gnatt chart.xlsx]
2024-09-26 links of diodes to choose from
2024-09-30 Added website of model for RGB LED
2024-09-30 Added RGB LED model
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2024-10-07 Add list of components to buy.
    [components.xlsx]
2024-10-07 Move components.xlsx to meetings folder.
    [components.xlsx]
2024-10-08 Fix date on last meeting.
    [components.xlsx]
2024-10-09 Update components list.
    [components.xlsx]
2024-10-11 Add datasheets for arduino nano every and atmega4809.
2024-10-11 Update components list in hardware folder.
    [components.xlsx]
2024-10-11 Add KiCad projects for individual rooms, door and control panel.
    [ControlPanel.kicad_pcb, ControlPanel.kicad_sch, Door.kicad_pcb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]
2024-10-11 Add schematic for room 2.
    [Room2.kicad_sch]
2024-10-13 Update and rename KiCad-tutorial.txt to KiCad-tutorial.md
2024-10-16 Room 3 schematic
    [room3.kicad_sch]
2024-10-16 Update room 3 schematic
    [Room3.kicad_sch]
2024-10-17 Update room 2 schematic.
    [Room2.kicad_sch]
2024-10-17 Create Scematic for Control Panel
    [ControlPanel.kicad_sch]
2024-10-17 Added custom Arduino every Symbol
2024-10-17 Change transistors in room 3 schematic
    [Room3.kicad_sch]
2024-10-17 Add smart home pinout in kicad.
    [SmartHomeSchematic.kicad_pcb, SmartHomeSchematic.kicad_sch]
2024-10-19 Combine partial schematics into one.
    [SmartHomeSchematic.kicad_sch]
2024-10-21 Move schematic and PCB design to schematic_and_PCB folder.
    [ControlPanel.kicad_pcb, ControlPanel.kicad_sch, Door.kicad_pcb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]
2024-10-21 Replace arduino nano every symbol with new symbol and add resistor values.
    [SmartHomeSchematic.kicad_sch]
2024-10-21 Change schematic as was agreed on a meeting, also change used pins.md.
    [SmartHomeSchematic.kicad_sch]
2024-10-23 Create Button case V1.pdf
    Added button casing blueprint
2024-10-27 Add floor 3D model.
    [Floor.stl]
2024-10-27 Update resistor values.
    [SmartHomeSchematic.kicad_sch]
2024-10-28 Update room 3 with calculations
    [Room3.kicad_sch]
2024-10-29 Added the basic model of the walls
    Added the basic model of the walls
    [walls.stl]
2024-10-29 updated version of the wall model with holes
    [walls2.stl]
2024-10-30 put windows on the walls model
    [walls_with_windows.stl]
2024-10-31 Updated calculations
    [Room3.kicad_sch]
2024-10-31 Update smarthome schematic with calculations
    [SmartHomeSchematic.kicad_sch]
2024-11-01 saved control panel schematic
2024-11-01 updated whole schematic with calculations
    [SmartHomeSchematic.kicad_sch]
2024-11-01 Update LCD PCB
    [LCD_PCB.kicad_pcb, LCD_PCB.kicad_sch]
2024-11-01 Update PCB LCD
    [LCD_PCB.kicad_pcb, LCD_PCB.kicad_sch, SmartHomeSchematic.kicad_sch]
2024-11-01 Add room 2 header file.
    [SmartHomeSchematic.kicad_sch]
2024-11-01 Finish LCD PCB
    [LCD_PCB.kicad_pcb, LCD_PCB.kicad_sch, LCD_PCB.step]
2024-11-06 Update bunch of stuff
    [LCD_PCB._model.step, LCD_PCB.kicad_pcb, LCD_PCB.kicad_sch]
2024-11-08 Add datasheets for arduino nano.
2024-11-08 Remove Arduino nano every files.
2024-11-08 Add floor and walls 3d model.
    [Walls v3.stl, floor.gcode.3mf]
2024-11-09 Update LCB PCB
    [LCD_PCB.kicad_pcb]
2024-11-11 Finalize LCD PCB
    [LCD_PCB-B_Cu.gbr, LCD_PCB-B_Mask.gbr, LCD_PCB-B_Paste.gbr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]
2024-11-14 Uploaded Arduino Main PCB
    [Arduino Main PCB.kicad_pcb, Arduino Main PCB.kicad_sch, test.kicad_pcb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]
2024-11-15 Fix bugs in adcpwm.c.
    [adcpwm.c]
2024-11-15 Code update for room 3
    [LCD_PCB-B_Cu.gbr, LCD_PCB-B_Mask.gbr, LCD_PCB-B_Paste.gbr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]
2024-11-21 LCD menu code
    [LCD_PCB.kicad_pcb]
2024-11-21 arduino main fin saved as final pcb
    [Arduino Main PCB.0.kicad_pcb, Arduino Main PCB.1.kicad_pcb, Arduino Main PCB.kicad_pcb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]
2024-11-26 Add 3D design of walls with images.
    [FloorPlates.dxf, front-and-back-walls.dxf, mid-walls.dxf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]
2024-11-26 Update Used pins.md
    Add pin for PIR sensor.
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2024-11-29 created display.c
    [Arduino Main PCB.kicad_pcb]
2024-12-04 Schematic of main PCB updated with Resistor values
    [Arduino Main PCB.kicad_pcb, Arduino Main PCB.kicad_sch]
2024-12-05 updated arduino main schematic
    [Arduino Main PCB.kicad_sch]
2024-12-05 Update pinout order of LCD PCB
    [LCD_PCB.kicad_pcb, LCD_PCB.kicad_sch]
2024-12-06 Fixes after testing on hardware.
    [adcpwm.c, control_panel.c, door.c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]
2024-12-06 Try to fix code for room 3
    [room_3.c]
2024-12-11 Do not control led using pins only pwm.
2024-12-11 Fix pwm.
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2024-12-11 Fix pwm 1.
2024-12-14 Implement menu responsiveness to changes in rooms and overall navigation.
    - add ability to change values in menu
    - correctly display enum values in menu
    - change values in menu using buttons (not potentiometer)
    - change values in menu in real time
    [door.c]
2024-12-16 Fix rooms and door, programs for checking buttons and controling lights.
    [door.c, room_1.c, room_2.c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]
2024-12-16 Some value specifier rewrite.
    [Arduino Main PCB.kicad_sch]
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2024-12-18 Add pcb cover file for printing
    [PcbCoverAndSpacers.gcode.3mf]
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2024-12-18 Try to fix pwm3_get_duty() function
    [adcpwm.c]
2024-12-18 Fix pwm3_get_duty and add pwm1_get_duty.
    [adcpwm.c, room_1.c]
2024-12-18 Fix pwm3_get_duty.
2024-12-18 Try to fix pwm3 get duty
    [adcpwm.c, main.c, room_3.c]
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2024-12-18 Fix pwm3_get_duty again.
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2024-12-21 Fix adcpwm.c hopefully final time.
    [adcpwm.c]
2024-12-21 Fix door light status.
    [door.c]
2024-12-21 Fix color changing in room 3.
    [room_3.c]
2024-12-21 Fix file element printing.
2024-12-22 Fix getting light intensity room 1.
    [adcpwm.c, room_1.c]
2024-12-22 Fix comments in control_panel.c.
    [control_panel.c]
2024-12-23 Fix get status of light in room 3.
    [room_3.c]
2024-12-23 Fix room 1 light switching.
    [room_1.c]
2024-12-23 Attempt to fix room 3 light status change using control panel.
    [room_3.c]
2024-12-24 Made the LCD PCB Schematic better readable
    [LCD_PCB.kicad_sch]
2024-12-29 Make schematic more readable.
    [Arduino Main PCB.kicad_pcb, Arduino Main PCB.kicad_sch]
2024-12-29 Some changes related to pdf export.
    [LCD_PCB.kicad_sch]
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2025-01-01 Added PCB cover file for printing
    [PCBcoverVersion2v2NEWFORPRINT.gcode.3mf, PcbCoverAndSpacers.gcode.3mf]
2025-01-02 Added budget table
    [budget.xlsx]
2025-01-02 Finalize report
    [contributionTable.xlsx]
2025-01-10 Copy files to Product folder.
    [Base.stl, FloorPlates.dxf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]
